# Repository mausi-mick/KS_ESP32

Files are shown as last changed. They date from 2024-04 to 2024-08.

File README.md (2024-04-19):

   Kennlinienschreiber mit ESP32

Hier möchte ich nur kurz die ESP32-Variante vorstellen.

Die vorher beschriebenen Versionen  -  auf Arduino NANO / ATMega328P   bzw. Arduino-EVERY basierend   - waren im Laufe der Entwicklung in mehrerer Hinsicht an ihre Grenzen gestossen:

    •     zu wenig Speicher
    •     zu wenig Pins
    •     relativ langsam
    •     Bluetooth nur über externe HW (HC05 /HC12)

Die ersten Tests waren dann aber etwas ernüchternd,  

Gerade die verwandten ADC’s (MCP3204) und DAC’s MCP4822 an SPI (VSPI) machten
Probleme., aber das scheint gelöst zu sein.

Ich verwende ein ESP-Modul mit 38 Pins, um möglichst viele Pins zur Verfügung zu haben für
die BUSSE (I2C, SPI), Schalter und Encoder und  RX/TX (z.B. zur Verbindung mit modif. Transistortester)

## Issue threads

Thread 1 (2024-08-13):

Guide for build

enzodello, 2024-08-13:
do I have to connect all the diagrams in the folder together?
which sketch should i load on esp32?
 could you describe what each .ino file is for?

mausi-mick, 2024-08-13:
Ad first You need the new Arduino IDE 2.3.2 ( I used version 1.8.13, but it was very slow) for the sketches ( .ino) and Header (.h) and the KiCad version 8.0 or higher for the schematics, pcbs, .

there are 3 "big" boards,

  ESP32_R ...      for the ESP32 (38 pin)
  UCE_Board_2  iwith DAC (for Uce / Uds) and the ADC and Power Amplifier TCA03722
  CCS_I2C         for the isolated precision Currentsource

and 2 small boards piggyback on the CCS_I2C board:

 CCS_Switch_BE_1            smallBoard with 4Photomos-Relais
 IC2_Adum_MCP4725_1  small Board with Adum-Isolator and DAC_MCP4725

Closed 2024-08-13.

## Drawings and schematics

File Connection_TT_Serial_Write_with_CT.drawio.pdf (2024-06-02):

# Connection AVR Transistor-Tester with Curve-Tracer

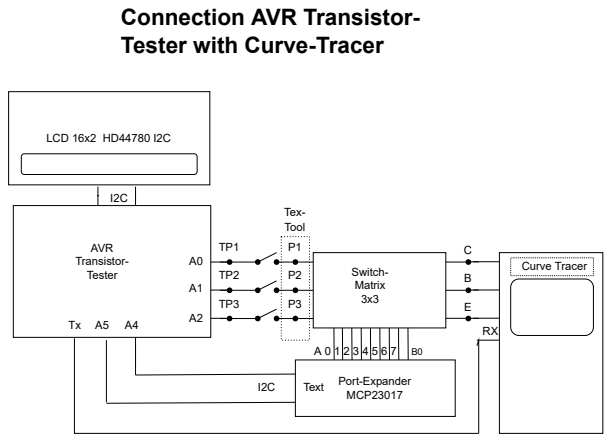
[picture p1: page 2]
Switch- Matrix 3x3; AVR Transistor- Tester; LCD 16x2 HD44780 I2C; Port-Expander; MCP23017 I2C; Text; Tex- Tool; Curve Tracer

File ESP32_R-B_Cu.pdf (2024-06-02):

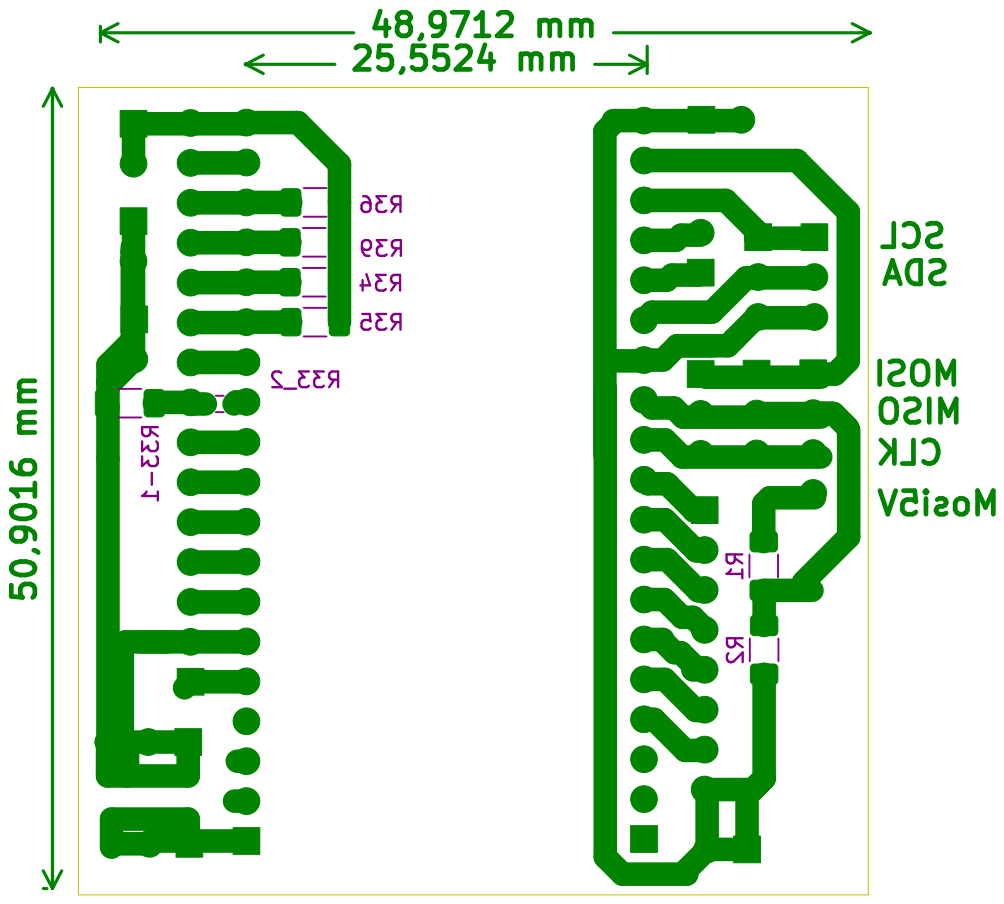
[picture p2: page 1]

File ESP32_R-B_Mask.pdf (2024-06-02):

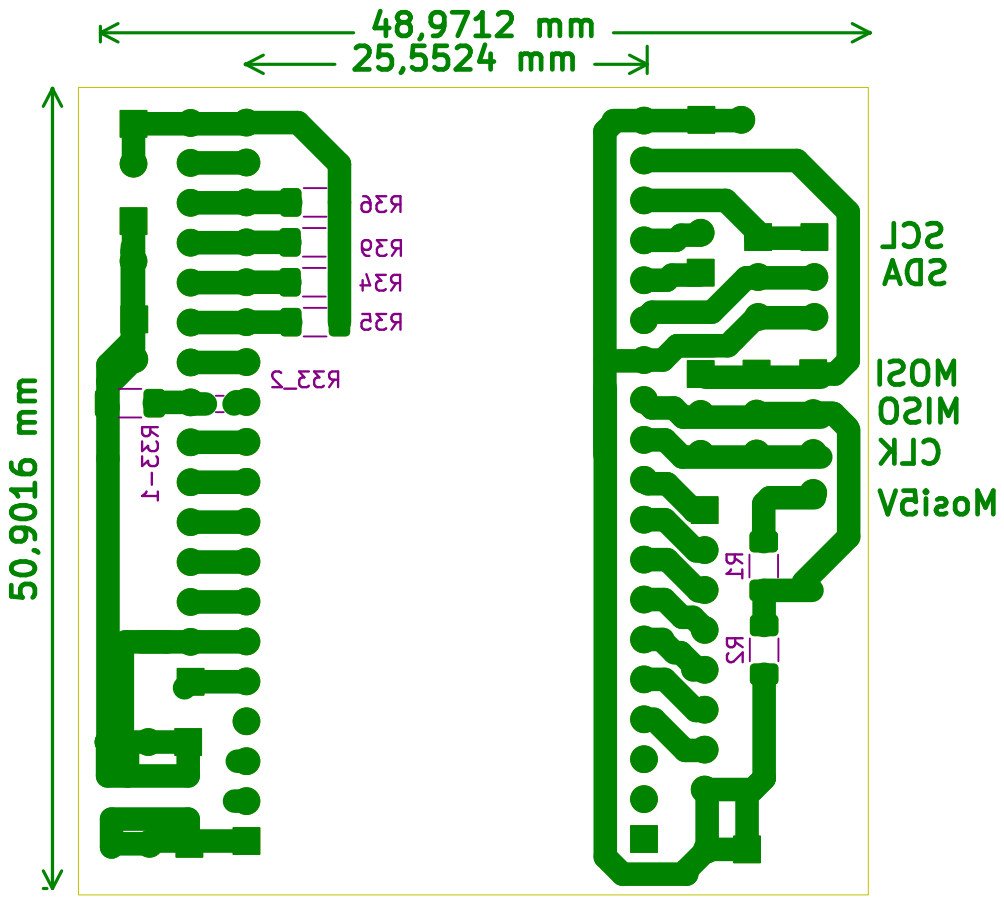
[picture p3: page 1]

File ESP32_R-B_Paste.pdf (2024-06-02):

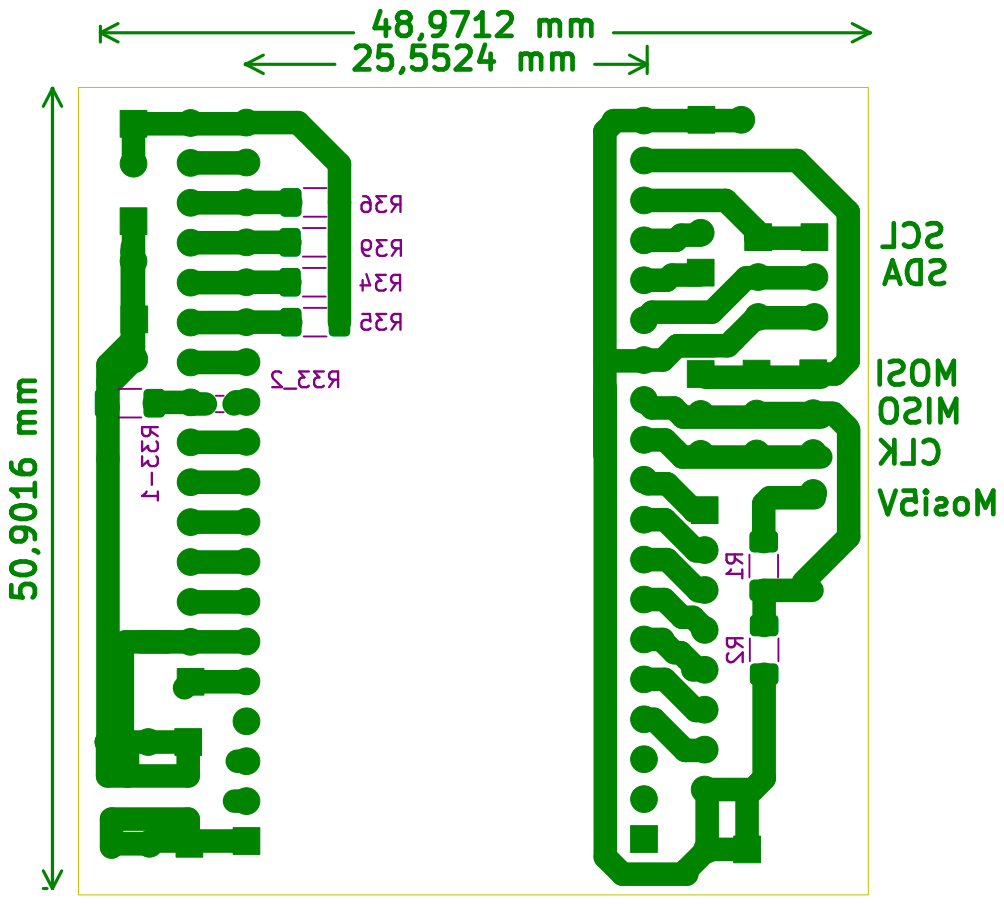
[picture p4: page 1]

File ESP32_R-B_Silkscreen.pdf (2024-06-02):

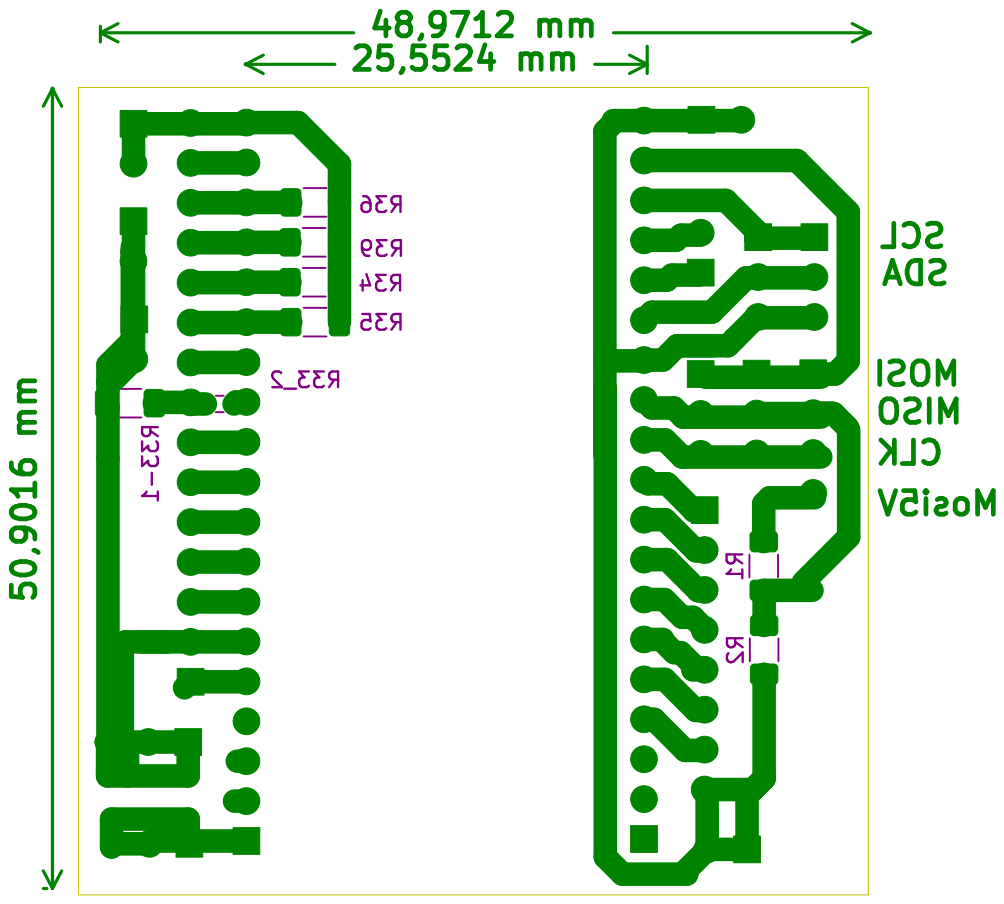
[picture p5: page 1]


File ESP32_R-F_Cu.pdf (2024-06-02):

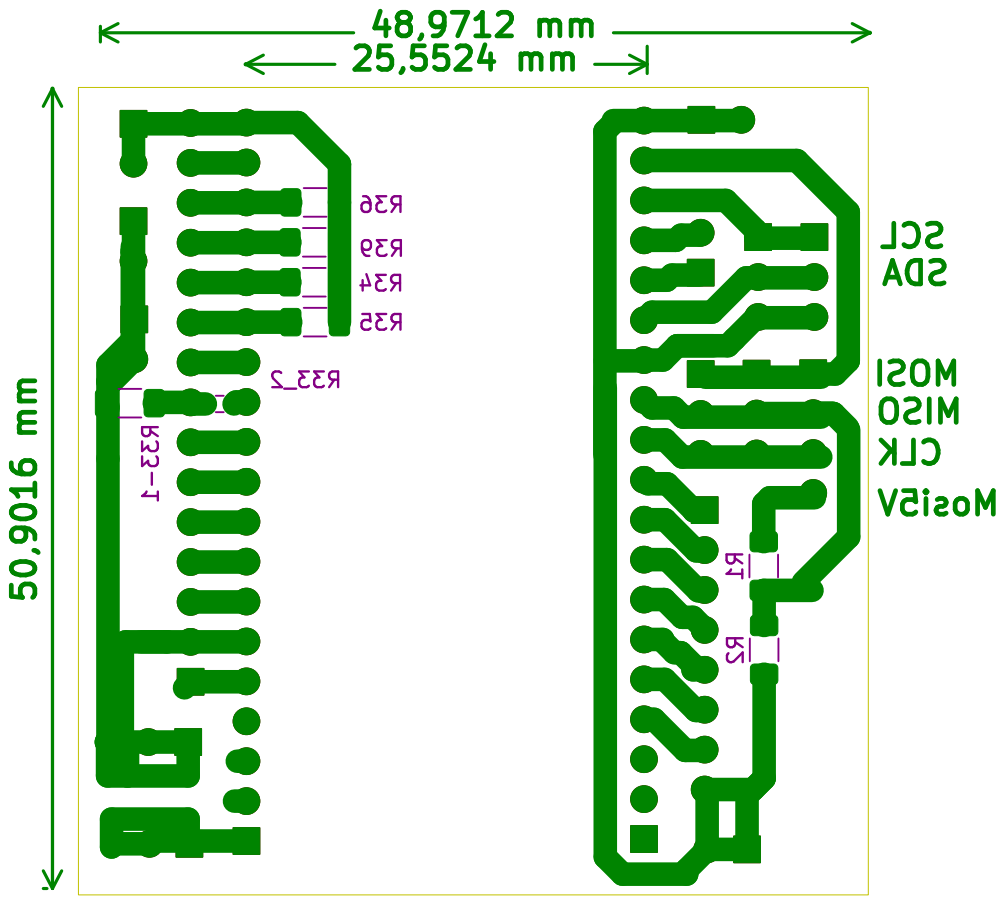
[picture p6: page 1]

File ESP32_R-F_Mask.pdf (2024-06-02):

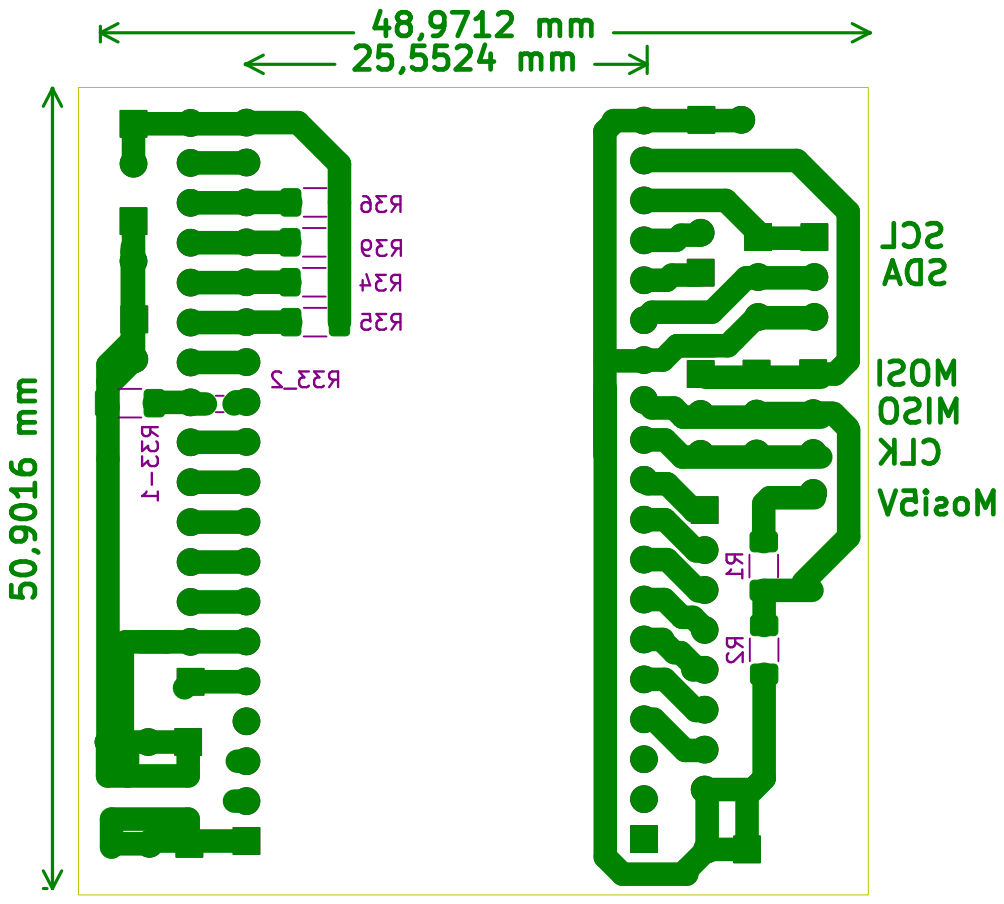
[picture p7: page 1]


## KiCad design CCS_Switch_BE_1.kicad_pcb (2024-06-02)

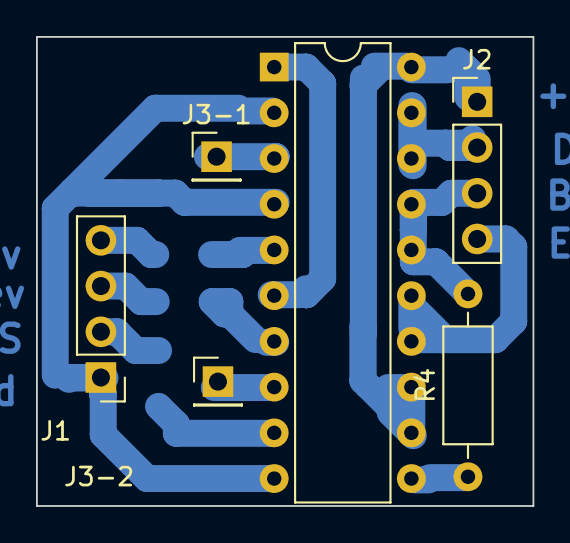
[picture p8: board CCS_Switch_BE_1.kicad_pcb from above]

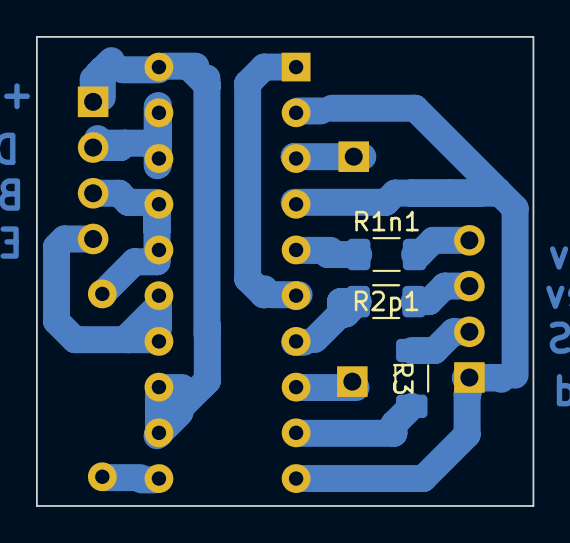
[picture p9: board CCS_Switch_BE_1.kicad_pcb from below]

Board: 2 copper layers, 27.6 x 26.1 mm, 9 parts (3 on the bottom side), 4 nets.

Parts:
DIL20: DIP-20_W7.62mm
J1: Switch n,p,Rg,Gndp; PinHeader_1x04_P2.54mm_Vertical
J2: Switch +30V,Drain-CCS,B,E; PinHeader_1x04_P2.54mm_Vertical
J3-1, J3-2: Br; PinHeader_1x01_P2.54mm_Vertical
R1n1, R2p1: 270; R_1206_3216Metric_Pad1.30x1.75mm_HandSolder
R3: 510; R_1206_3216Metric_Pad1.30x1.75mm_HandSolder
R4: 10k; R_Axial_DIN0207_L6.3mm_D2.5mm_P10.16mm_Horizontal

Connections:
unnamed: J1.2, R3.1
unnamed: J1.3, R2p1.1
unnamed: J1.4, R1n1.2
unnamed: J2.3, R4.2

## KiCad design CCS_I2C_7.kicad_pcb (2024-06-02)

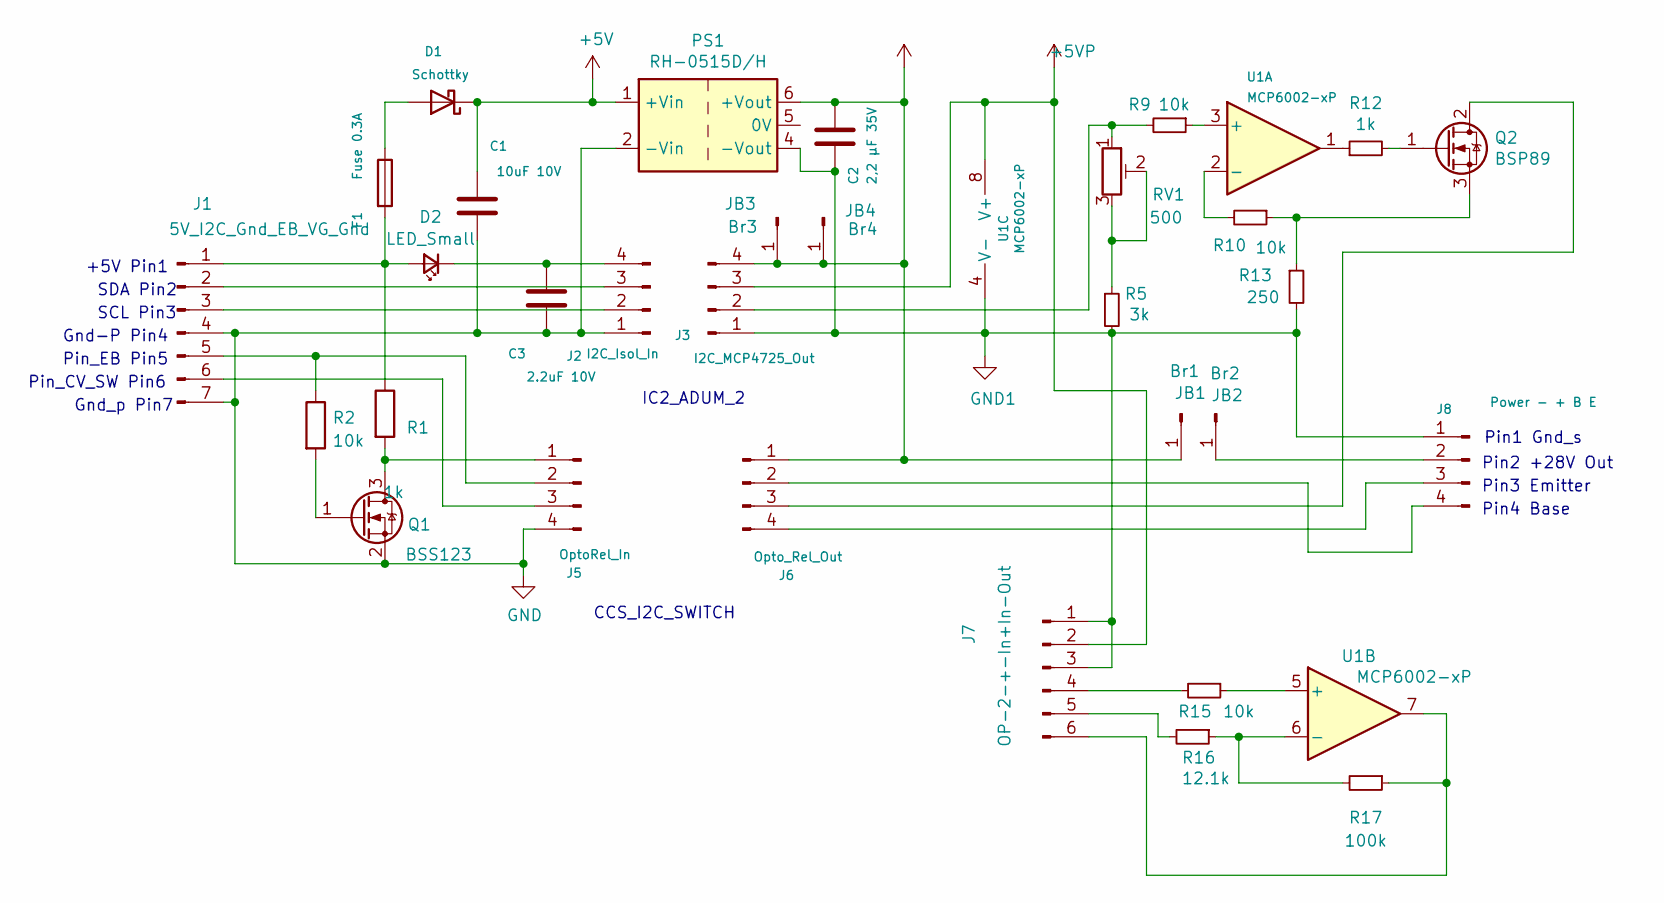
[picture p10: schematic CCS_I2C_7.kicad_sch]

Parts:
C1: 10uF 10V; C_1812_4532Metric_Pad1.57x3.40mm_HandSolder
C2: 2,2 µF 35V; C_1812_4532Metric_Pad1.57x3.40mm_HandSolder
C3: 2.2uF 10V; C_1206_3216Metric_Pad1.33x1.80mm_HandSolder
D1: Schottky; D_1206_3216Metric_Pad1.42x1.75mm_HandSolder
D2: LED_Small; LED_D3.0mm
F1: Fuse 0.3A; Fuse_1206_3216Metric_Pad1.42x1.75mm_HandSolder
J1: 5V_I2C_Gnd_EB_VG_Gnd; PinHeader_1x07_P2.54mm_Horizontal
J2: I2C_Isol_In; PinSocket_1x04_P2.54mm_Vertical
J3: I2C_MCP4725_Out; PinSocket_1x04_P2.54mm_Vertical
J5: OptoRel_In; PinSocket_1x04_P2.54mm_Vertical
J6: Opto_Rel_Out; PinSocket_1x04_P2.54mm_Vertical
J7: OP-2-+-In+In-Out; PinHeader_1x06_P2.54mm_Horizontal
J8: Power - + B E; PinHeader_1x04_P2.54mm_Horizontal
JB1: Br1; PinHeader_1x01_P2.54mm_Vertical
JB2: Br2; PinHeader_1x01_P2.54mm_Vertical
JB3: Br3; PinHeader_1x01_P2.54mm_Vertical
JB4: Br4; PinHeader_1x01_P2.54mm_Vertical
PS1: RH-0515D/H; Converter_DCDC_XP_POWER-IHxxxxSH_THT
Q1: BSS123; SOT-23
Q2: BSP89; SOT-223-3_TabPin2
R1: 1k; R_2010_5025Metric_Pad1.40x2.65mm_HandSolder
R2: 10k; R_1206_3216Metric_Pad1.30x1.75mm_HandSolder
R5: 3k; R_Axial_DIN0207_L6.3mm_D2.5mm_P10.16mm_Horizontal
R9, R10, R15: 10k; R_Axial_DIN0207_L6.3mm_D2.5mm_P10.16mm_Horizontal
R12: 1k; R_Axial_DIN0207_L6.3mm_D2.5mm_P10.16mm_Horizontal
R13: 250; R_Axial_DIN0207_L6.3mm_D2.5mm_P10.16mm_Horizontal
R16: 12.1k; R_Axial_DIN0207_L6.3mm_D2.5mm_P10.16mm_Horizontal
R17: 100k; R_Axial_DIN0207_L6.3mm_D2.5mm_P10.16mm_Horizontal
RV1: 500; Potentiometer_ACP_CA6-H2,5_Horizontal
U1: MCP6002-xP; DIP-8_W7.62mm_LongPads

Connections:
+5V: C1.1, D1.1 (K), PS1.1 (+Vin)
+5VP: J3.3, J7.2, U1.8 (V+)
+28V: C2.1, J3.4, J6.1, JB1.1, JB3.1, JB4.1, PS1.6 (+Vout)
GND: C1.2, C3.2, J1.4, J1.7, J2.1, J5.4, PS1.2 (-Vin), Q1.2 (S)
GND1: C2.2, J3.1, J7.1, J7.3, J8.1, PS1.4 (-Vout), R5.2, R13.2, U1.4 (V-)
unnamed: D1.2 (A), F1.1
unnamed: D2.2 (A), F1.2, J1.1, R1.1
unnamed: C3.1, D2.1 (K), J2.4
unnamed: J1.2, J2.3
unnamed: J1.3, J2.2
unnamed: J1.5, J5.2, R2.1
unnamed: J1.6, J5.3
unnamed: J3.2, R9.2, RV1.1
unnamed: J5.1, Q1.3 (D), R1.2
unnamed: J6.2, J8.4
unnamed: J6.3, Q2.2 (D)
unnamed: J6.4, J8.3
unnamed: J7.4, R15.2
unnamed: J7.5, R16.2
unnamed: J7.6, R17.1, U1.7
unnamed: J8.2, JB2.1
unnamed: Q1.1 (G), R2.2
unnamed: Q2.1 (G), R12.2
unnamed: Q2.3 (S), R10.1, R13.1
unnamed: R5.1, RV1.2, RV1.3
unnamed: R12.1, U1.1
unnamed: R9.1, U1.3 (+)
unnamed: R10.2, U1.2 (-)
unnamed: R15.1, U1.5 (+)
unnamed: R16.1, R17.2, U1.6 (-)

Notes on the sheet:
Pin_EB Pin5
IC2_ADUM_2
+5V Pin1
Gnd-P Pin4
SDA Pin2
Pin2 +28V Out
SCL Pin3
Pin4 Base
Gnd_p Pin7
Pin1 Gnd_s
Pin3 Emitter
CCS_I2C_SWITCH
Pin_CV_SW Pin6

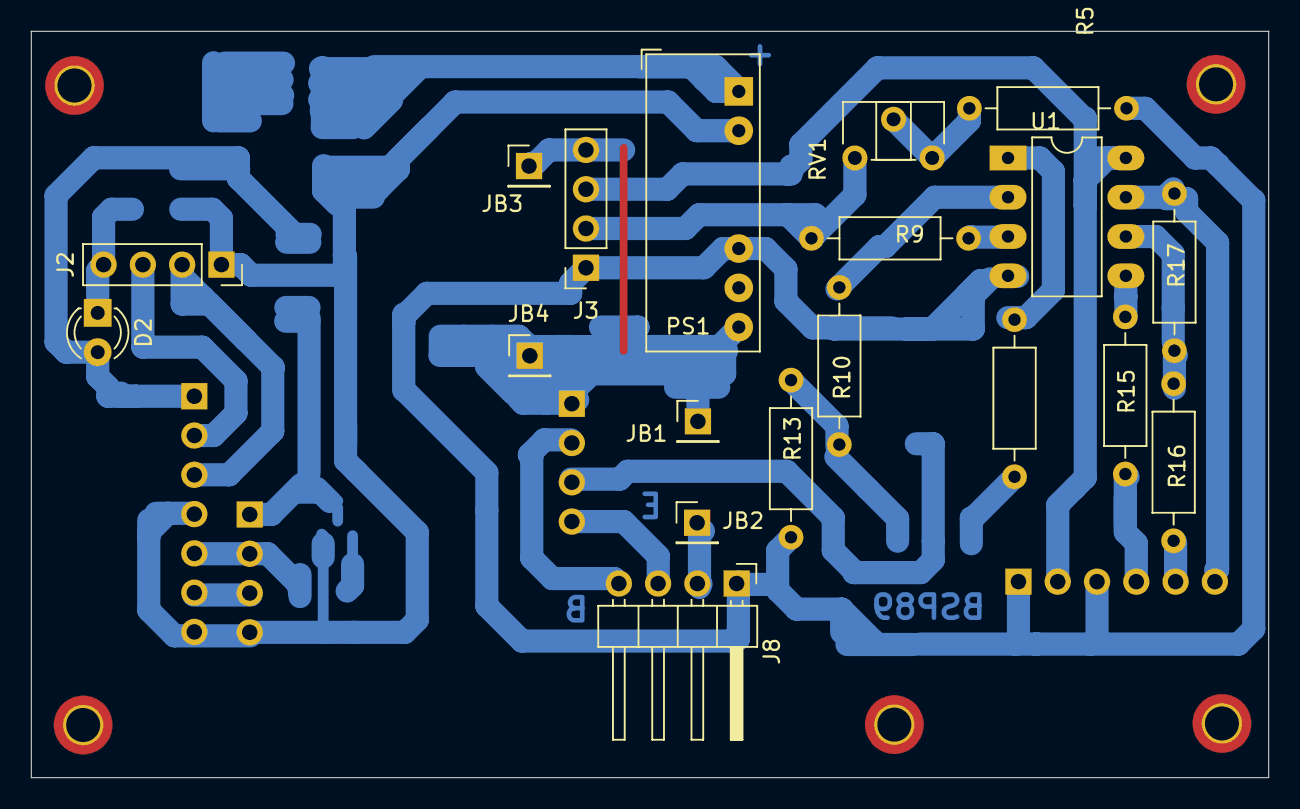
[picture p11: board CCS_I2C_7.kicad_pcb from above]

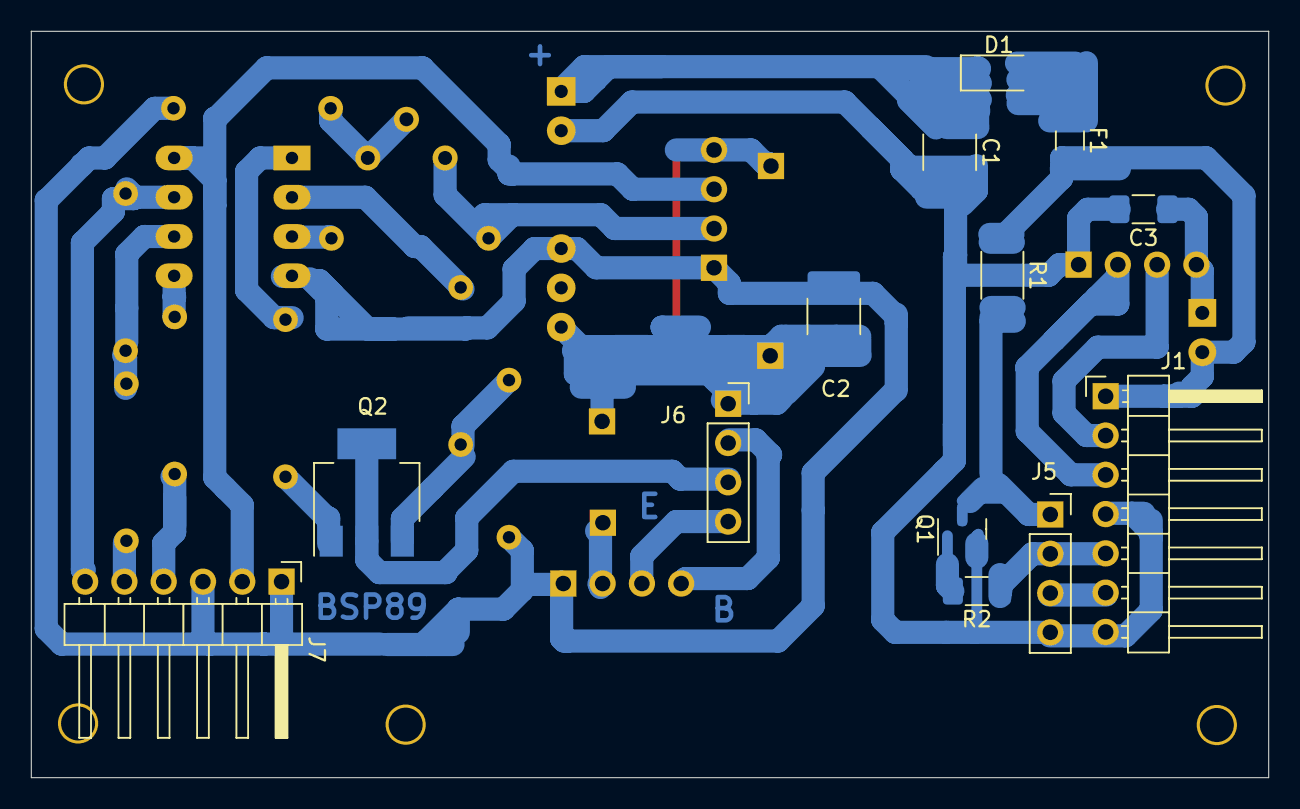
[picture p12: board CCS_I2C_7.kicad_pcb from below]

Board: 2 copper layers, 80.0 x 48.3 mm, 32 parts (13 on the bottom side), 30 nets.

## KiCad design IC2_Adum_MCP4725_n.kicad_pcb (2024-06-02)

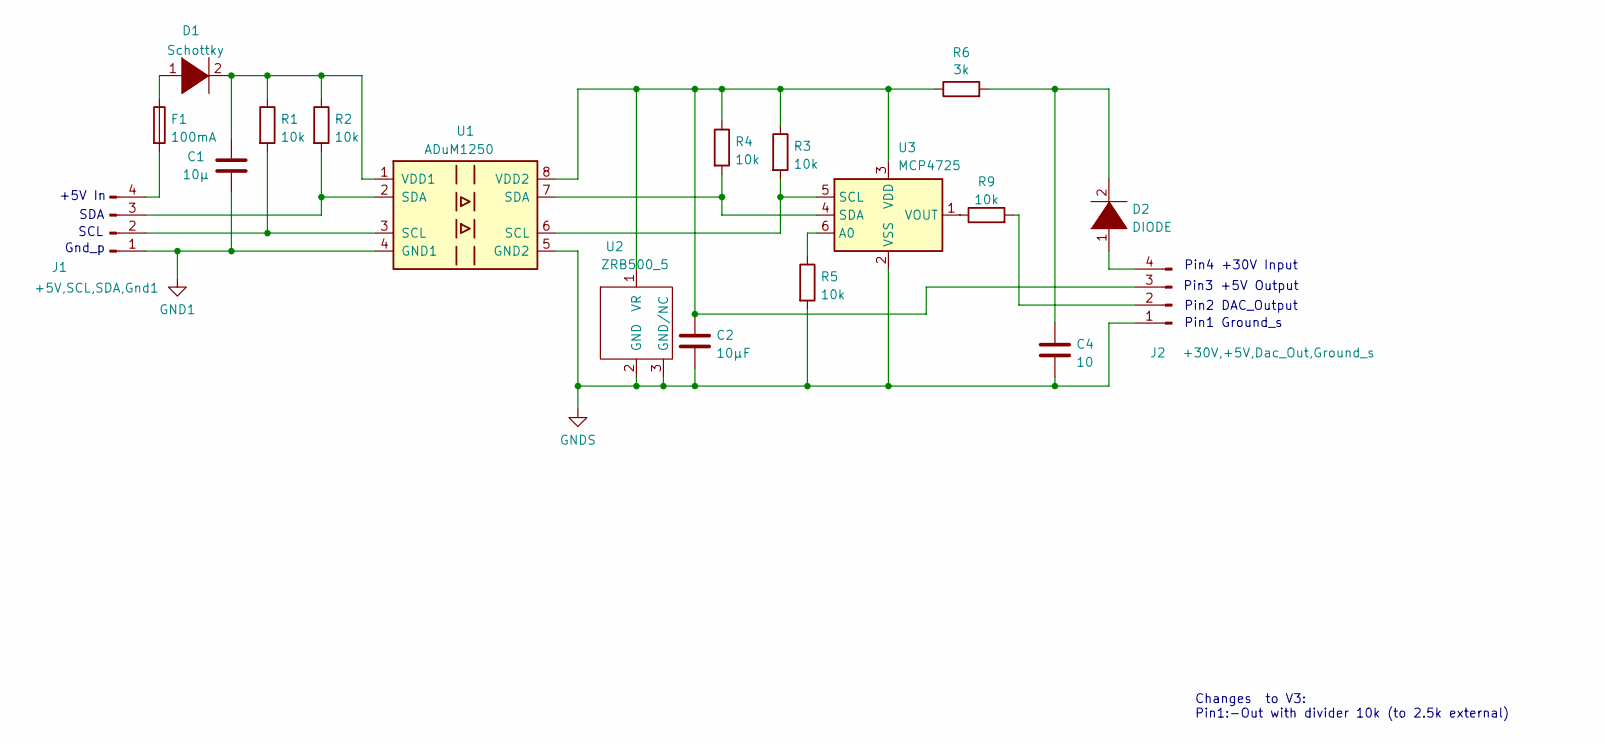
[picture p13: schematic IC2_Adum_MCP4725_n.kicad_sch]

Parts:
C1: 10µ; C_1206_3216Metric_Pad1.33x1.80mm_HandSolder
C2: 10µF; C_1206_3216Metric_Pad1.33x1.80mm_HandSolder
C4: 10; C_1206_3216Metric_Pad1.33x1.80mm_HandSolder
D1: Schottky; D_1206_3216Metric_Pad1.42x1.75mm_HandSolder
D2: DIODE; D_0805_2012Metric_Pad1.15x1.40mm_HandSolder
F1: 100mA; Fuse_1206_3216Metric_Pad1.42x1.75mm_HandSolder
J1: +5V,SCL,SDA,Gnd1; PinHeader_1x04_P2.54mm_Vertical
J2: +30V,+5V,Dac_Out,Ground_s; PinHeader_1x04_P2.54mm_Vertical
R1, R2, R3, R4, R5, R9: 10k; R_1206_3216Metric_Pad1.30x1.75mm_HandSolder
R6: 3k; R_1206_3216Metric_Pad1.30x1.75mm_HandSolder
U1: ADuM1250; SOIC-8_3.9x4.9mm_P1.27mm
U2: ZRB500_5; SOT-23-3
U3: MCP4725; SOT-23-6

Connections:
GND1: C1.2, J1.1, U1.4 (GND1)
GNDS: C2.2, C4.2, J2.1, R5.2, U1.5 (GND2), U2.2 (GND), U2.3 (GND/NC), U3.2 (VSS)
unnamed: C1.1, D1.2 (A), R1.1, R2.1, U1.1 (VDD1)
unnamed: D1.1 (K), F1.1
unnamed: C4.1, D2.2 (A), R6.2
unnamed: D2.1 (K), J2.4
unnamed: J1.2, R1.2, U1.3 (SCL)
unnamed: J1.3, R2.2, U1.2 (SDA)
unnamed: F1.2, J1.4
unnamed: J2.2, R9.2
unnamed: C2.1, J2.3, R3.1, R4.1, R6.1, U1.8 (VDD2), U2.1 (VR), U3.3 (VDD)
unnamed: R5.1, U3.6 (A0)
unnamed: R3.2, U1.6 (SCL), U3.5 (SCL)
unnamed: R4.2, U1.7 (SDA), U3.4 (SDA)
unnamed: R9.1, U3.1 (VOUT)

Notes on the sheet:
Pin2 DAC_Output
Changes to V3: Pin1:-Out with divider 10k (to 2.5k external)
+5V In
Pin3 +5V Output
Gnd_p
SDA
Pin1 Ground_s
SCL
Pin4 +30V Input

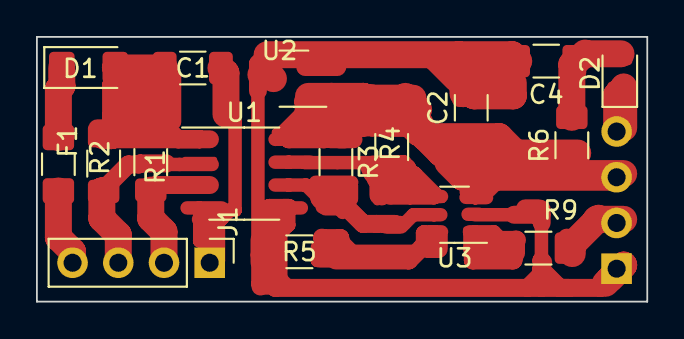
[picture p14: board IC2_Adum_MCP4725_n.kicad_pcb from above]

Board: 2 copper layers, 33.9 x 14.7 mm, 18 parts (1 on the bottom side), 15 nets.

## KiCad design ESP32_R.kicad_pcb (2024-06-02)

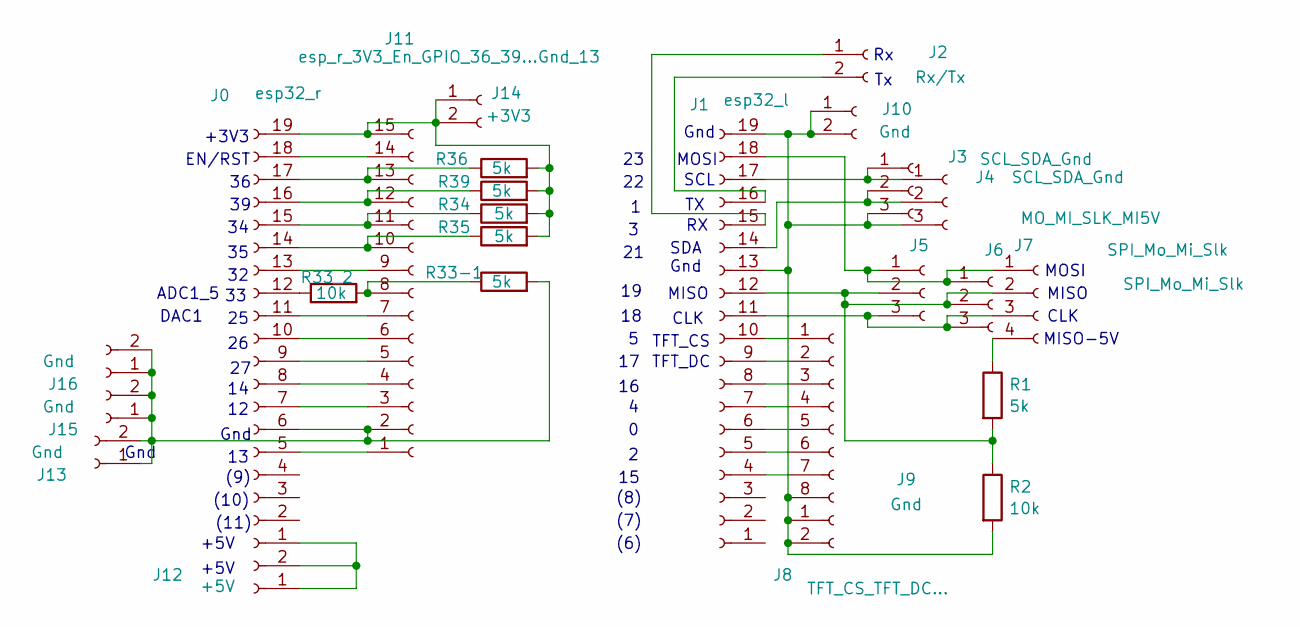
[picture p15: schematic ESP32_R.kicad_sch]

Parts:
J0: esp32_r; PinSocket_1x19_P2.54mm_Vertical
J1: esp32_l; PinSocket_1x19_P2.54mm_Vertical
J2: Rx/Tx; PinSocket_1x02_P2.54mm_Vertical
J3, J4: SCL_SDA_Gnd; PinSocket_1x03_P2.54mm_Vertical
J5, J6: SPI_Mo_Mi_Slk; PinSocket_1x03_P2.54mm_Vertical
J7: MO_MI_SLK_MI5V; PinHeader_1x04_P2.54mm_Vertical
J8: TFT_CS_TFT_DC...; PinSocket_1x08_P2.54mm_Vertical
J9, J10, J13, J15, J16: Gnd; PinSocket_1x02_P2.54mm_Vertical
J11: esp_r_3V3_En_GPIO_36_39...Gnd_13; PinHeader_1x15_P2.54mm_Vertical
J12: +5V; PinSocket_1x02_P2.54mm_Vertical
J14: +3V3; PinSocket_1x02_P2.54mm_Vertical
R1, R33-1, R34, R35, R36, R39: 5k; R_1206_3216Metric_Pad1.30x1.75mm_HandSolder
R2: 10k; R_1206_3216Metric_Pad1.30x1.75mm_HandSolder
R33_2: 10k; R_0603_1608Metric_Pad0.98x0.95mm_HandSolder

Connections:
unnamed: J0.1, J12.1, J12.2
unnamed: J0.5, J11.1
unnamed: J0.6, J11.2, J13.1, J13.2, J15.1, J15.2, J16.1, J16.2, R33-1.2
unnamed: J0.7, J11.3
unnamed: J0.8, J11.4
unnamed: J0.9, J11.5
unnamed: J0.10, J11.6
unnamed: J0.11, J11.7
unnamed: J0.12, R33_2.1
unnamed: J0.13, J11.9
unnamed: J0.14, J11.10, R35.1
unnamed: J0.15, J11.11, R34.1
unnamed: J0.16, J11.12, R39.1
unnamed: J0.17, J11.13, R36.1
unnamed: J0.18, J11.14
unnamed: J0.19, J11.15, J14.1, J14.2, R34.2, R35.2, R36.2, R39.2
unnamed: J1.4, J8.7
unnamed: J1.5, J8.6
unnamed: J1.6, J8.5
unnamed: J1.7, J8.4
unnamed: J1.8, J8.3
unnamed: J1.9, J8.2
unnamed: J1.10, J8.1
unnamed: J1.11, J5.3, J6.3, J7.3
unnamed: J1.12, J5.2, J6.2, J7.2, R1.2, R2.1
unnamed: J1.13, J1.19, J3.3, J4.3, J8.8, J9.1, J9.2, J10.1, J10.2, R2.2
unnamed: J1.14, J3.2, J4.2
unnamed: J1.15, J2.1
unnamed: J1.16, J2.2
unnamed: J1.17, J3.1, J4.1
unnamed: J1.18, J5.1, J6.1, J7.1
unnamed: J7.4, R1.1
unnamed: J11.8, R33-1.1, R33_2.2

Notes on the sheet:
Gnd
EN/RST
MOSI
TFT_CS
(10)
ADC1_5
MISO-5V
CLK
(6)
DAC1
(7)
(11)
TFT_DC
MISO
(8)
(9)
SDA
SCL
+3V3
+5V

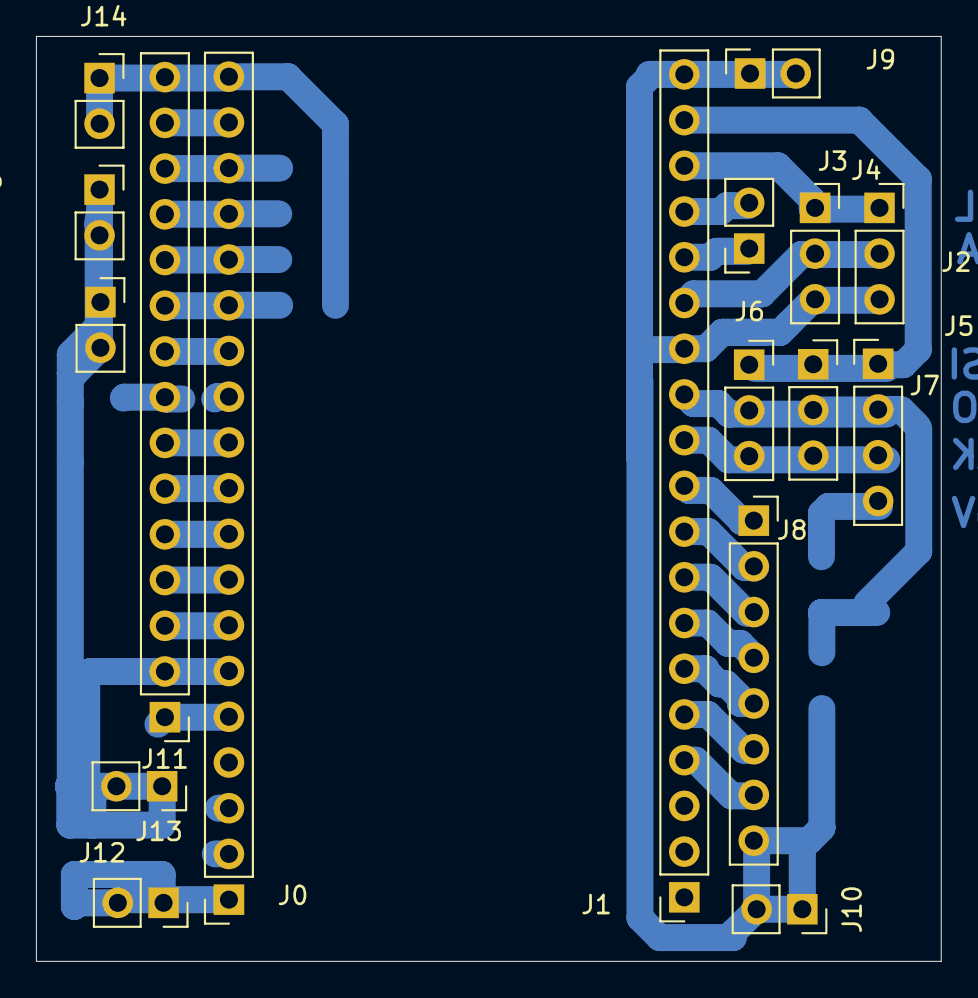
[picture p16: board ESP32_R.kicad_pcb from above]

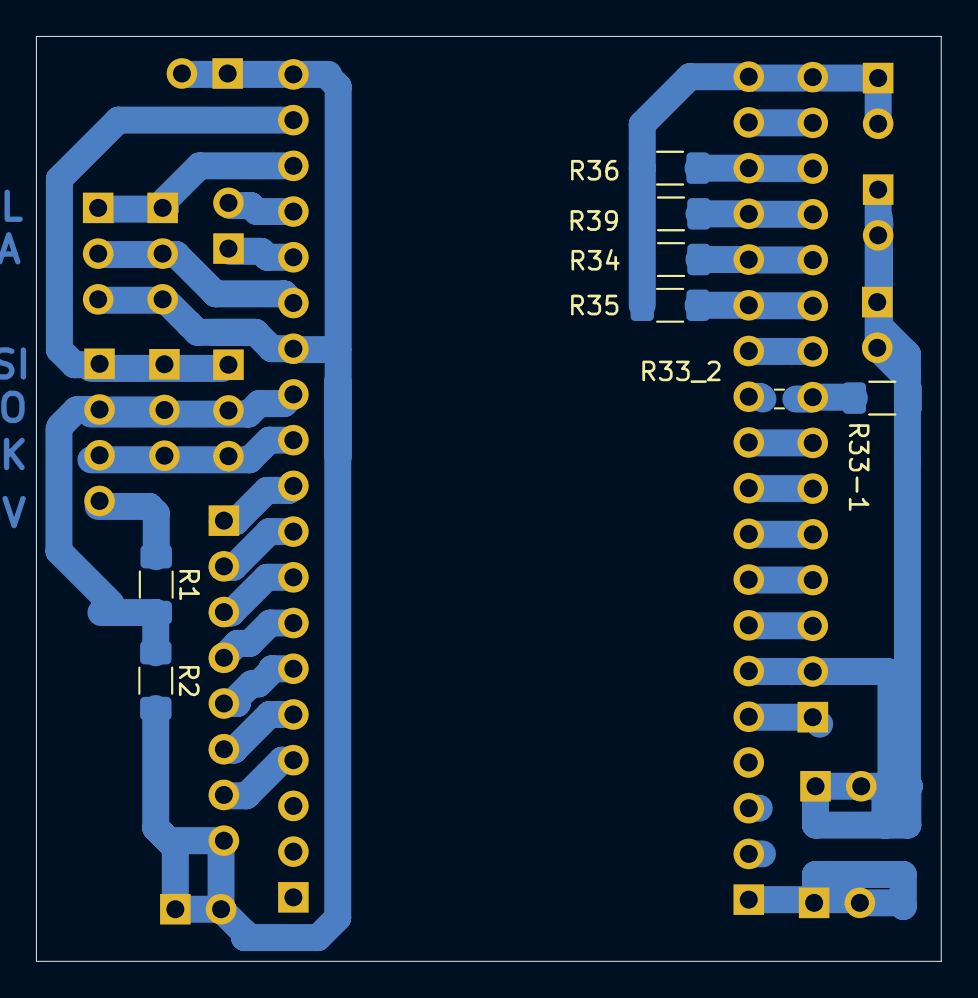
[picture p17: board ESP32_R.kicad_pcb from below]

Board: 2 copper layers, 50.3 x 51.4 mm, 25 parts (8 on the bottom side), 33 nets.

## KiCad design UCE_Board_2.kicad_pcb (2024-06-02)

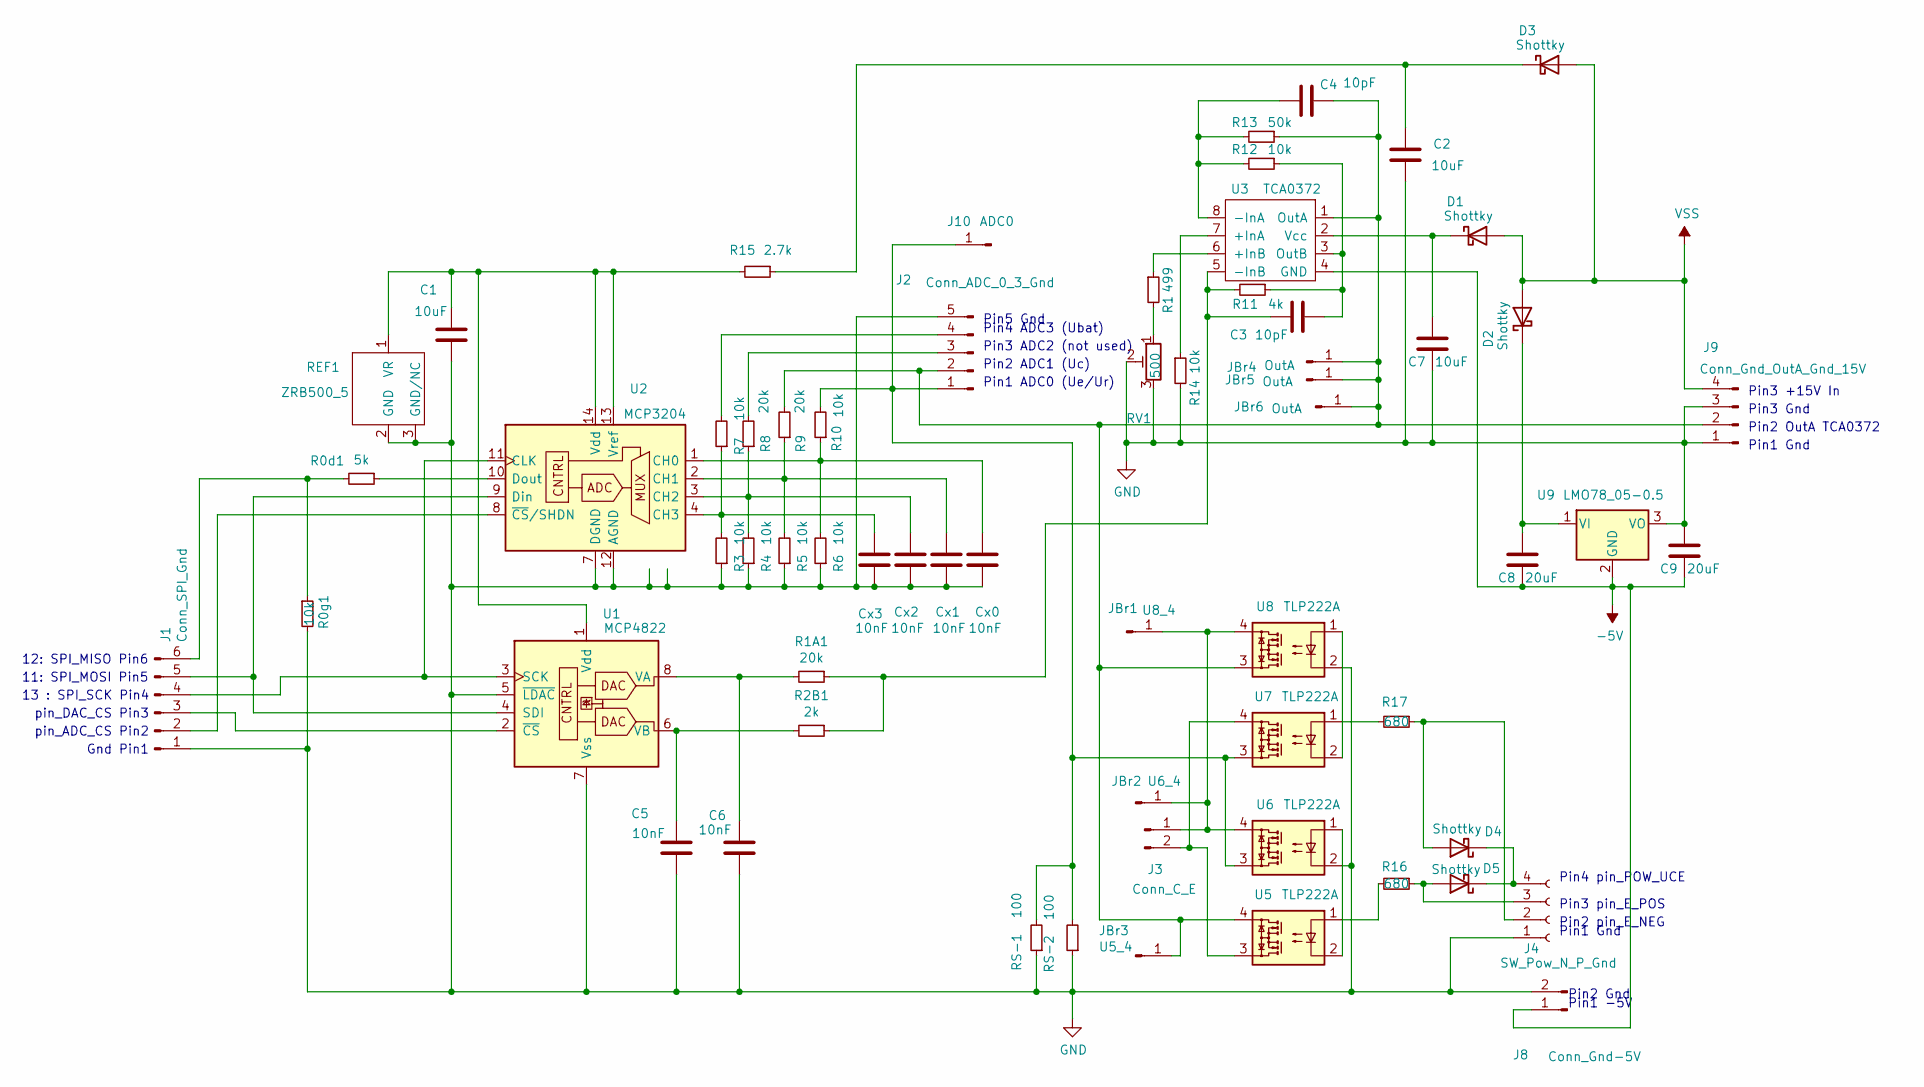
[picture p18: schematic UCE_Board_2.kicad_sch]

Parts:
C1: 10uF; C_1210_3225Metric_Pad1.33x2.70mm_HandSolder
C2: 10uF; C_1812_4532Metric_Pad1.57x3.40mm_HandSolder
C3: 10pF; C_Axial_L5.1mm_D3.1mm_P7.50mm_Horizontal
C4: 10pF; C_Rect_L9.0mm_W2.5mm_P7.50mm_MKT
C5, C6: 10nF; C_1206_3216Metric_Pad1.33x1.80mm_HandSolder
C7: 10uF; C_1206_3216Metric_Pad1.33x1.80mm_HandSolder
C8, C9: 20uF; C_1812_4532Metric_Pad1.57x3.40mm_HandSolder
Cx0, Cx1, Cx2, Cx3: 10nF; C_0805_2012Metric_Pad1.18x1.45mm_HandSolder
D1, D2, D3: Shottky; D_1206_3216Metric_Pad1.42x1.75mm_HandSolder
D4, D5: Shottky; D_0603_1608Metric_Pad1.05x0.95mm_HandSolder
J1: Conn_SPI_Gnd; PinHeader_1x06_P2.54mm_Horizontal
J2: Conn_ADC_0_3_Gnd; PinHeader_1x05_P2.54mm_Vertical
J3: Conn_C_E; PinHeader_1x02_P2.54mm_Horizontal
J4: SW_Pow_N_P_Gnd; PinHeader_1x04_P2.54mm_Horizontal
J8: Conn_Gnd-5V; PinHeader_1x02_P2.54mm_Vertical
J9: Conn_Gnd_OutA_Gnd_15V; PinHeader_1x04_P2.54mm_Horizontal
J10: ADC0; PinHeader_1x01_P2.54mm_Vertical
JBr1: U8_4; PinHeader_1x01_P2.54mm_Vertical
JBr2: U6_4; PinHeader_1x01_P2.54mm_Vertical
JBr3: U5_4; PinHeader_1x01_P1.00mm_Vertical
JBr4: OutA; PinHeader_1x01_P1.00mm_Vertical
JBr5, JBr6: OutA; PinHeader_1x01_P1.27mm_Vertical
R0d1: 5k; R_1206_3216Metric_Pad1.30x1.75mm_HandSolder
R0g1, R12: 10k; R_Axial_DIN0204_L3.6mm_D1.6mm_P7.62mm_Horizontal
R1: 499; R_Axial_DIN0207_L6.3mm_D2.5mm_P10.16mm_Horizontal
R1A1: 20k; R_Axial_DIN0207_L6.3mm_D2.5mm_P10.16mm_Horizontal
R2B1: 2k; R_Axial_DIN0207_L6.3mm_D2.5mm_P10.16mm_Horizontal
R3, R4, R5, R6, R7, R10: 10k; R_1206_3216Metric_Pad1.30x1.75mm_HandSolder
R8, R9: 20k; R_1206_3216Metric_Pad1.30x1.75mm_HandSolder
R11: 4k; R_Axial_DIN0207_L6.3mm_D2.5mm_P10.16mm_Horizontal
R13: 50k; R_Axial_DIN0207_L6.3mm_D2.5mm_P10.16mm_Horizontal
R14: 10k; R_Axial_DIN0207_L6.3mm_D2.5mm_P10.16mm_Horizontal
R15: 2.7k; R_Axial_DIN0207_L6.3mm_D2.5mm_P10.16mm_Horizontal
R16, R17: 680; R_Axial_DIN0207_L6.3mm_D2.5mm_P10.16mm_Horizontal
REF1: ZRB500_5; SOT-23
RS-1, RS-2: 100; R_Axial_DIN0207_L6.3mm_D2.5mm_P10.16mm_Horizontal
RV1: 500; Potentiometer_ACP_CA9-H2,5_Horizontal
U1: MCP4822; DIP-8_W7.62mm_LongPads
U2: MCP3204; DIP-14_W7.62mm
U3: TCA0372; DIP-8_W7.62mm_LongPads
U5, U6, U7, U8: TLP222A; DIP-4_W7.62mm
U9: LMO78_05-0.5; TO-220-3_Vertical

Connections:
-5V: C8.2, C9.2, J8.1, U3.4 (GND), U9.2 (GND)
GND: C1.2, C2.2, C5.1, C6.1, C7.2, C9.1, Cx0.1, Cx1.1, Cx2.1, Cx3.1, J1.1, J2.5, J4.1, J8.2, J9.1, J9.3, R0g1.2, R3.1, R4.1, R5.1, R6.1, R14.2, REF1.2 (GND), REF1.3 (GND/NC), RS-1.1, RS-2.1, RV1.2, RV1.3, U1.5 (~LDAC), U1.7 (Vss), U2.5 (NC), U2.6 (NC), U2.7 (DGND), U2.12 (AGND), U6.2, U8.2, U9.3 (VO)
unnamed: C7.1, D1.1 (K), U3.2 (Vcc)
unnamed: C8.1, D2.1 (K), U9.1 (VI)
unnamed: C2.1, D3.1 (K), R15.1
unnamed: D4.2 (A), J4.2, R17.1
unnamed: D4.1 (K), D5.1 (K), J4.4
unnamed: D5.2 (A), J4.3, R16.1
unnamed: J1.2, U2.8 (~CS/SHDN)
unnamed: J1.3, U1.2 (~CS)
unnamed: J1.4, U1.3 (SCK), U2.11 (CLK)
unnamed: J1.5, U1.4 (SDI), U2.9 (Din)
unnamed: J1.6, R0d1.2, R0g1.1
unnamed: C4.1, J2.2, J9.2, JBr3.1, JBr4.1, JBr5.1, JBr6.1, R9.2, R13.1, U3.1 (OutA), U5.4, U8.3
unnamed: J2.3, R8.2
unnamed: J2.4, R7.2
unnamed: J3.1, JBr1.1, JBr2.1, U6.4, U8.4
unnamed: J3.2, U5.3, U7.4
unnamed: J2.1, J10.1, R10.2, RS-1.2, RS-2.2, U6.3, U7.3
unnamed: R1.2, RV1.1
unnamed: R16.2, U5.1
unnamed: R17.2, U7.1
unnamed: C1.1, R15.2, REF1.1 (VR), U1.1 (Vdd), U2.13 (Vref), U2.14 (Vdd)
unnamed: C6.2, R1A1.2, U1.8 (VA)
unnamed: C5.2, R2B1.2, U1.6 (VB)
unnamed: Cx0.2, R6.2, R10.1, U2.1 (CH0)
unnamed: Cx1.2, R5.2, R9.1, U2.2 (CH1)
unnamed: Cx2.2, R4.2, R8.1, U2.3 (CH2)
unnamed: Cx3.2, R3.2, R7.1, U2.4 (CH3)
unnamed: R0d1.1, U2.10 (Dout)
unnamed: R14.1, U3.7 (+InA)
unnamed: R1.1, U3.6 (+InB)
unnamed: C4.2, R12.2, R13.2, U3.8 (-InA)
unnamed: C3.2, R1A1.1, R2B1.1, R11.2, U3.5 (-InB)
unnamed: C3.1, R11.1, R12.1, U3.3 (OutB)
unnamed: U5.2, U6.1
unnamed: U7.2, U8.1
VSS: D1.2 (A), D2.2 (A), D3.2 (A), J9.4

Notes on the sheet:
pin_ADC_CS Pin2
Pin1 Gnd
Pin5 Gnd
Gnd Pin1
Pin2 pin_E_NEG
Pin2 OutA TCA0372
Pin4 pin_POW_UCE
12: SPI_MISO Pin6
Pin2 ADC1 (Uc)
pin_DAC_CS Pin3
Pin3 pin_E_POS
Pin3 ADC2 (not used)
Pin2 Gnd
Pin1 ADC0 (Ue/Ur)
Pin3 +15V In
Pin1 -5V
Pin3 Gnd
11: SPI_MOSI Pin5
Pin4 ADC3 (Ubat)
13 : SPI_SCK Pin4

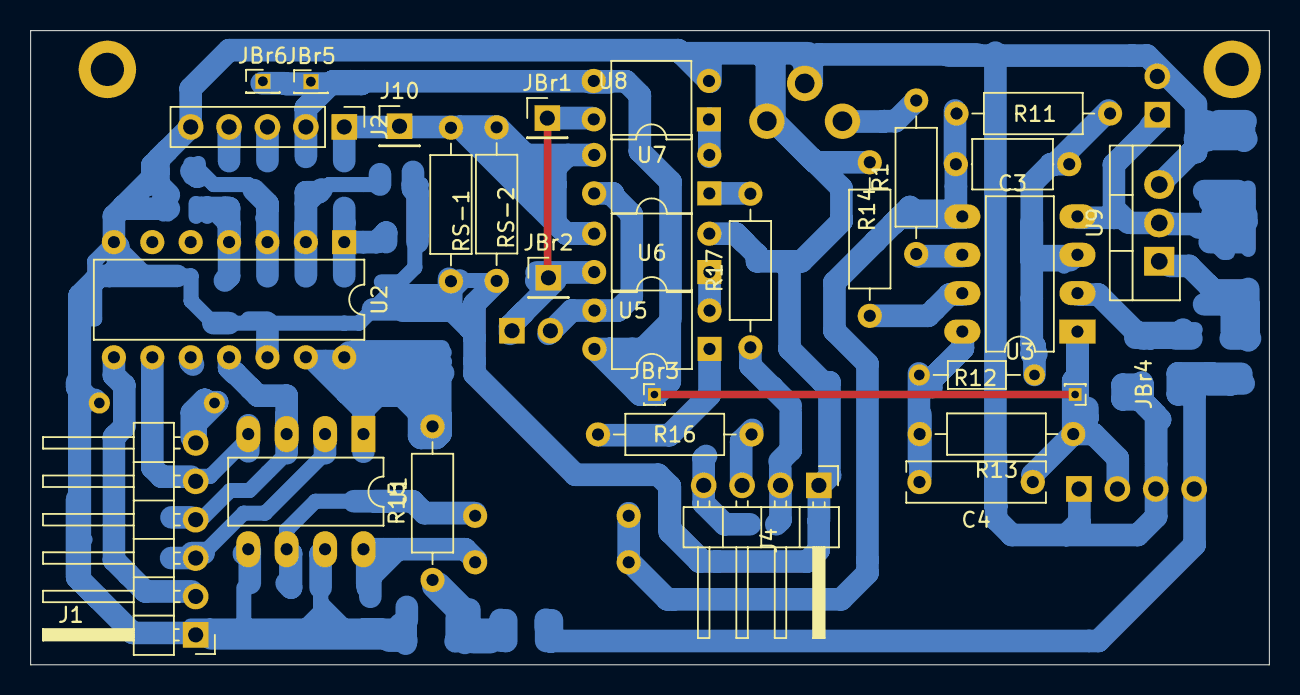
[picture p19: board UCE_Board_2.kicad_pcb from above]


Board: 2 copper layers, 82.0 x 42.0 mm, 63 parts (33 on the bottom side), 38 nets.

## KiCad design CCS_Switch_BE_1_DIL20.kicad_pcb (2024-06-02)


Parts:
J1: Switch n,p,Rg,Gndp; PinHeader_1x04_P2.54mm_Vertical
J2: Switch +30V,Drain-CCS,B,E; PinHeader_1x04_P2.54mm_Vertical
J3-1, J3-2: Br; PinHeader_1x01_P2.54mm_Vertical
R1n1, R2p1: 270; R_1206_3216Metric_Pad1.30x1.75mm_HandSolder
R3: 510; R_1206_3216Metric_Pad1.30x1.75mm_HandSolder
R4: 10k; R_Axial_DIN0207_L6.3mm_D2.5mm_P10.16mm_Horizontal
SW1, SW2, SW3, SW4, SW5: TLP222A; DIP-4_W7.62mm

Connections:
GND: J1.1, SW1.2, SW2.2, SW5.2
unnamed: J1.2, R3.1
unnamed: J1.3, R2p1.1
unnamed: J1.4, R1n1.2
unnamed: J2.1, SW1.4, SW4.3, SW5.4
unnamed: J2.2, SW1.3, SW2.4
unnamed: J2.3, R4.2, SW2.3, SW3.4
unnamed: J2.4, SW3.3, SW4.4
unnamed: J3-1.1, SW2.1
unnamed: J3-2.1, SW4.2
unnamed: R1n1.1, SW3.1
unnamed: R2p1.2, SW4.1
unnamed: R3.2, SW5.1
unnamed: R4.1, SW5.3
unnamed: SW1.1, SW3.2

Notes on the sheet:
Base
SW_pDev
SW_CCS_CVS
SW_nDev
+30V
Drain
Emitter
Gnd



Board: 2 copper layers, 28.2 x 30.2 mm, 13 parts (3 on the bottom side), 15 nets.

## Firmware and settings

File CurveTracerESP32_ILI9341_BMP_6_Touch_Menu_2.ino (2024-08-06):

//---------------------------------------------------------------
// 
//--------------------------------------------------------------------------------------------------------------------------------------
// 2023_03_16 copy from CurveTracer_2_DacV_20, but other dividers on A0,A1,A2,A3
// 2023_03_18 second encoder, only PIN_EB (not PIN_BE) for p-devices (pin 1 CCS normal high, switch automatically to low, if PIN_EB high)
// 2023_03-21 sign µ in 2/1 on position of tile (~)
// 2024_01_04 CurveTracerRP2040_Adafruit_ILI9341_SD_01: change µ-proceesor to RP2040
// 2024_01_04 CurveTracerRP2040_Adafruit_ILI9341_SD_02: test isr and encoder ("pio_encoder")
// 2024_01_16 CurveTracerESP32_ILI9341_SD_03: SD-Card , SerialBT instead of HM010
// 2024_04_20 CurveTracerESP32_ILI9341_BMP_5: SD-Card , SerialBT, new libs for MCP3204 and MCP4822, isr update
// 2024_06_01 CurveTracerESP32_ILI9341_BMP_6: s_zen: suppress zeo-point x-scale, start curve from volt s_zen
//--------------------------------------------------------------------------------------------------------------------------------------

//#define DEBUG 1
#if DEBUG == 1
#define debug(x)   Serial.print(x);
#define debugb(x)  Serial.print(x);Serial.print(" ");
#define debugln(x) Serial.print(x);Serial.print("\n");
#define debuglf()  Serial.print("\n");
#else
#define debug(x)
#define debugb(x)
#define debugln(x)
#define debuglf()
#endif

#define TOUCH
#define DAC_INT
#define BLUE_T
#define BMP
#define IEPROM
#define SD_C
//#define NAME_D
//#define OSCI

#include <Arduino.h>

#include <SPI.h>

#ifdef SD_C
#include <SD.h>  //###################
#endif

//SPISettings settingsT(10000000, MSBFIRST, SPI_MODE0); // TFT 12 MHz, cpu 240 MHz

#include "TFT_eSPI.h"
#include "Free_Fonts.h"   // Include the header file attached to this sketch

TFT_eSPI tft = TFT_eSPI();       // Invoke custom library

#define TFT_GREY 0x5AEB

#ifdef IEPROM         // internal EEPROM
#include "EEPROM.h"
#define EEPROM_SIZE 256
#endif

#include "MCP_ADC.h"

// ESP32 PINS for HSPI :  CLK=14, MISO=12, MOSI=13
// ESP32 PINS for VSPI :  CLK=18, MISO=19, MOSI=23

MCP3204 MCP_A;    // use HWSPI  on ESP32 (apparently VSPI)

#include <Wire.h>

#include "Adafruit_MCP4725.h"

Adafruit_MCP4725 dac_i2c;        // 12 bit DAC (I2C Addrees : 60

#ifdef BLUE_T
#include "BluetoothSerial.h"
BluetoothSerial SerialBT;
#endif

//#define EEPROM_I2C_ADDRESS 0x50  // EEPROM 24LC64 I2C Address  //24LC

const int pin_DAC_CS        =  0;  // MCP4822 DAC
const int TX_D0             =  1;  // TxD0 for send data to PC
const int pin_ADC_CS        =  2;  // MCP3204 ADC//GPIO2  on board LED, must be left floating or LOW to enter flashing mode
const int RX_D0             =  3;  // RxD0 for TT
const int pin_EB            =  4;  // switch emitter / base (polarity)
//const int TFT_CS          =  5;  // V-SPI CS
//                          =  6;  // Flash
//                          =  7;  // Flash
//                          =  8;  // Flash
//                          =  9;  // Flash
//                          = 10;  // Flash
//                          = 11;  // Flash
const int pin_E_NEG         = 12;  // switch Emitter/Source/Kathode to Rs (near Gnd)   ,Collector ... to Output TCA0372)(for npn-Tran,n-MOS
//free                      = 13;  // free 
const int pin_E_POS         = 14;  // switch Emitter/Source/Kathode to (output max+12V) (for pnp-Tran,p-MOS,p-JFET,Diode(backward biased))
const int pin_CV_SW         = 15;  // switch Constant-Current to Constant-Voltage for (Mos-Fet and J-Fet)
#ifdef SD_C
const int pin_SD_CS         = 16;  // SD_CS
#endif
//const int TFT_DC          = 17;  // V-SPI DC
//const int TFT_CLK         = 18;  // V-SPI CLK
//const int TFT_MISO        = 19;  // V-SPI MISO
//                           = 20;  // ??? na
//const int I2C_SDA         = 21;  // SDA I2C for MCP4725 (DAC-base)
//const int I2C_SCL         = 22;  // SCL I2C for MCP4725 (DAC-base)
//const int TFT_MOSI        = 23;  // V-SPI MOSI
//                           = 24;  // ??? na
#ifdef OSCI
#ifdef DAC_INT 
const int pin_DAC1          = 25;  // DAC1
#endif
#endif  
const int pin_TOUCH_IRQ     = 26;  // Touch-IRQ test   // DAC2                  
const int pin_TOUCH_CS      = 27;  // Touch-CS here not used
//                           = 28;  // ??? na
//                           = 29;  // ??? na
//                           = 30;  // ??? na
//                           = 31;  // ??? na
const int Pin_32_BUT        = 32;  // PushButton  ISR-Pin
#ifdef OSCI
const int pin_ADC1_5        = 33;  // ADC1_5
#endif 
const int pin_ENC1_A        = 34;  // Encoder-1-A ISR-Pin, Pull-Up 10k ?
const int pin_ENC1_B        = 35;  // Encoder-1-B IST-Pin, Pull-Up 10k ?
const int pin_ENC2_A        = 36;  // Encoder-2-A ISR-Pin, Pull-Up 10k ?
const int pin_ENC2_B        = 39;  // Encoder-2-B ISR-Pin, Pull-Up 10k ?

const int pin_DAC_LDAC      = -1;  // MCP4822

//#include "MCP4822.h"
//MCP4822 dac = MCP4822(pin_DAC_CS);//,pin_DAC_LDAC);

#include "MCP_DAC.h"

//  HSPI uses default   SCLK=14, MISO=12, MOSI=13, SELECT=15
//  VSPI uses default   SCLK=18, MISO=19, MOSI=23, SELECT=5
SPIClass * myspi = new SPIClass(VSPI);
MCP4822 MCP_D(myspi);  // HW SPI

const int TFT_WID   =  320;
const int TFT_HGT   =  240;
#ifdef OSCI

int16_t inpBuf2[TFT_WID];
int16_t inpBuf3[TFT_WID];

uint8_t newBuf2[TFT_WID], oldBuf2[TFT_WID];
uint8_t newBuf3[TFT_WID], oldBuf3[TFT_WID];
int pos = 0;                      // the next position in the value array to read
int count = 0;                    // the total number of times through the loop
unsigned long readStartTime = 0;  // time when the current sampling started
int lastStart = 0;                // the sample at which drawing started last time (need to know this to clear the old line properly)
int16_t val_A1 = 0,val_A2,val_A3;
// Used by vsprintf.
//char buffer[32];
uint16_t SineValues[256];       // an array to store our values for sine

#endif

//const int ADC_MAX = 4095; // 12 bit MCP3402 1024; // 10 bit arduino UNO
//const int DAC_MAX = 4095;
const int tsd       = 1000;

const int mAmax       = 50; // Ic for top of screen
const int Vmax        = 12; // 12V right end of screen
const uint16_t col_t[] = {TFT_CYAN, TFT_YELLOW, TFT_MAGENTA,/* TFT_BRIGHTBLUE,*/ TFT_ORANGE,
                          TFT_PINK, /*TFT_LIGHTBLUE, TFT_LIGHTRED,*/ TFT_WHITE
                         };

const float count_to_mv   = 5020.0 / 4096.0;    // = 1.2129=Vref/maxcount ADC  //Vref = 5.02V ?? not 4.968
//const float adc_refmaxcnt = 0.0049512; //4.0*5.07/4096.0;  // MC3204  -Reference      = U-5V/12bit ADC; divider 4: 30k/10k
//const float adc0_refmaxcnt = 0.0024756; // 4949; //2.0*5.07/4096.0;  // MC3204  -Reference      = U-5V/12bit ADC; divider 2: 10k/10k A0
//const float adc1_refmaxcnt = 0.0037134; // 4949; //3.0*5.07/4096.0;  // MC3204  -Reference      = U-5V/12bit ADC; divider 3: 20k/10k A1
//const float adc_refmaxcnt = 1.110.0/1024.0;   // Internal-Reference NANO = 1.1V/10bit ADC; // divider 4.25V/1.1V ?
//const float adc_refmaxcnt = 4.41545/1024.0;   // normal  -Reference NANO = U-5V/10bit ADC; // ca 4.42V on USB
//const float adc_refmaxcnt = 4.0*5.07/4098.0;  // MC3204  -Reference      = U-5V/12bit ADC; divider
//const char seper = ',';  // seperator for Bluetooth-transfer


uint8_t bmpPNP[] PROGMEM = {
  21, 0, // width
  30, 0, // height
  0x3F, 0xFF, 0xF9, 0xFF, 0xFF, 0xCF, 0xFF, 0xFE, 0x7F, 0xFF, 0xF1, 0xFF, 0x3F, 0xC7, 0xF9, 0xFF,
  0x1F, 0xCF, 0xFC, 0x7E, 0x7F, 0xF1, 0xF3, 0xFF, 0xC7, 0x9F, 0xFF, 0x1C, 0xFF, 0xFC, 0x67, 0xFF,
  0xF1, 0x3F, 0xFF, 0xC1, 0xFF, 0xFF, 0x00, 0x1F, 0xFC, 0x00, 0xFF, 0x93, 0xFF, 0xF0, 0x9F, 0xFE,
  0x0C, 0xFF, 0xC0, 0x67, 0xFC, 0x07, 0x3F, 0xF0, 0x39, 0xFF, 0x83, 0xCF, 0xF8, 0x1E, 0x7F, 0x8D,
  0xF3, 0xF8, 0xFF, 0x9F, 0xCF, 0xFF, 0xFE, 0x7F, 0xFF, 0xF3, 0xFF, 0xFF, 0x9F, 0xFF, 0xFC
};

uint8_t bmpNPN[] PROGMEM = {
  21, 0, // width
  30, 0, // height
  0xFF, 0xFF, 0xE7, 0xFF, 0xFF, 0x3F, 0xFF, 0xF9, 0xFF, 0xFF, 0xCF, 0xE7, 0xFC, 0x7F, 0x3F, 0xC7,
  0xF9, 0xFC, 0x7F, 0xCF, 0xC7, 0xFE, 0x7C, 0x7F, 0xF3, 0xC7, 0xFF, 0x9C, 0x7F, 0xFC, 0xC7, 0xFF,
  0xE4, 0x7F, 0xFF, 0x07, 0xFC, 0x00, 0x7F, 0xE0, 0x03, 0xFF, 0xFE, 0x0F, 0xFF, 0xF2, 0x3B, 0xFF,
  0x98, 0x9F, 0xFC, 0xE0, 0x7F, 0xE7, 0x83, 0xFF, 0x38, 0x0F, 0xF9, 0x80, 0x7F, 0xCF, 0x01, 0xFE,
  0x7E, 0x0F, 0xF3, 0xFC, 0x3F, 0xFF, 0xF9, 0xFF, 0xFF, 0xCF, 0xFF, 0xFE, 0x7F, 0xFF, 0xF0
};

uint8_t bmpNMOSFET[] PROGMEM = {
  23, 0, // width
  34, 0, // height
  0xFF, 0xFF, 0xF9, 0xFF, 0xFF, 0xF3, 0xFF, 0xFF, 0xE7, 0xFF, 0xFF, 0xCF, 0xFF, 0xFF, 0x9F, 0xFF,
  0xFF, 0x3F, 0xFF, 0xFE, 0x7F, 0xFF, 0xFC, 0xFE, 0x60, 0x01, 0xFC, 0xC0, 0x03, 0xF9, 0x9F, 0xFF,
  0xF3, 0x3F, 0xFF, 0xE7, 0xFF, 0xFF, 0xCF, 0xFB, 0xFF, 0x99, 0xC7, 0xFF, 0x32, 0x0F, 0xFE, 0x60,
  0x01, 0xFC, 0xC0, 0x03, 0xF9, 0x90, 0x67, 0xF3, 0x38, 0xCF, 0xE7, 0xFD, 0x9F, 0xCF, 0xFF, 0x3F,
  0x99, 0xFE, 0x7F, 0x33, 0xFC, 0x00, 0x60, 0x00, 0x00, 0xC0, 0x03, 0xFF, 0xFF, 0xE7, 0xFF, 0xFF,
  0xCF, 0xFF, 0xFF, 0x9F, 0xFF, 0xFF, 0x3F, 0xFF, 0xFE, 0x7F, 0xFF, 0xFC, 0xFF, 0xFF, 0xF9, 0xFF,
  0xFF, 0xF0
};

uint8_t bmpPMOSFET[] PROGMEM = {

  23, 0, // width
  34, 0, // height
  0x3F, 0xFF, 0xFE, 0x7F, 0xFF, 0xFC, 0xFF, 0xFF, 0xF9, 0xFF, 0xFF, 0xF3, 0xFF, 0xFF, 0xE7, 0xFF,
  0xFF, 0xCF, 0xFF, 0xFF, 0x9F, 0xFF, 0xFF, 0x00, 0x0C, 0xFE, 0x00, 0x19, 0xFF, 0xFF, 0x33, 0xFF,
  0xFE, 0x67, 0xFF, 0xFF, 0xCF, 0xFF, 0xBF, 0x9F, 0xFC, 0x73, 0x3F, 0xE0, 0xE6, 0x7F, 0x80, 0x0C,
  0xFE, 0x00, 0x19, 0xFC, 0x07, 0x33, 0xF9, 0x8E, 0x67, 0xF3, 0xDF, 0xCF, 0xE7, 0xFF, 0x9F, 0xCF,
  0xF3, 0x3F, 0x9F, 0xE6, 0x7F, 0x00, 0x0C, 0x00, 0x00, 0x18, 0x00, 0xFF, 0xFF, 0xF9, 0xFF, 0xFF,
  0xF3, 0xFF, 0xFF, 0xE7, 0xFF, 0xFF, 0xCF, 0xFF, 0xFF, 0x9F, 0xFF, 0xFF, 0x3F, 0xFF, 0xFE, 0x7F,
  0xFF, 0xFC
};

uint8_t bmpNJFET[] PROGMEM = {
  21, 128, // width (run-length encoded)
  30, 0, // height
  0x02, 0x13, 0x02, 0x13, 0x02, 0x13, 0x02, 0x13, 0x02, 0x13, 0x02, 0x13, 0x02, 0x13, 0x02, 0x13, 0x02, 0x05, 0x02, 0x0C,
  0x02, 0x05, 0x02, 0x0C, 0x09, 0x0C, 0x09, 0x13, 0x02, 0x13, 0x02, 0x13, 0x02, 0x13, 0x02, 0x06, 0x01, 0x0C, 0x02, 0x04,
  0x03, 0x0C, 0x02, 0x02, 0x05, 0x05, 0x2C, 0x05, 0x02, 0x02, 0x05, 0x05, 0x02, 0x05, 0x02, 0x04, 0x03, 0x05, 0x02, 0x0D,
  0x01, 0x05, 0x02, 0x13, 0x02, 0x13, 0x02, 0x13, 0x02, 0x13, 0x02, 0x13, 0x02, 0x13, 0x02, 0x13
};

uint8_t bmpPJFET[] PROGMEM = {
  21, 128, // width (run-length encoded)
  30, 0, // height
  0x00, 0x13, 0x02, 0x13, 0x02, 0x13, 0x02, 0x13, 0x02, 0x13, 0x02, 0x13, 0x02, 0x13, 0x02, 0x13, 0x02, 0x0C, 0x02, 0x05,
  0x02, 0x0C, 0x02, 0x05, 0x02, 0x0C, 0x09, 0x0C, 0x09, 0x0C, 0x02, 0x13, 0x02, 0x13, 0x02, 0x0F, 0x01, 0x03, 0x02, 0x0D,
  0x03, 0x03, 0x02, 0x0B, 0x05, 0x03, 0x02, 0x07, 0x2A, 0x04, 0x05, 0x03, 0x02, 0x05, 0x02, 0x06, 0x03, 0x03, 0x02, 0x05,
  0x02, 0x08, 0x01, 0x0A, 0x02, 0x13, 0x02, 0x13, 0x02, 0x13, 0x02, 0x13, 0x02, 0x13, 0x02, 0x13, 0x02, 0x13, 0x02
};

uint8_t bmpPDiodeBig[] PROGMEM = {
  20, 128, // width run-length encoded
  24, 0, // height
  0x00, 0x09, 0x02, 0x12, 0x02, 0x12, 0x02, 0x12, 0x02, 0x12, 0x02, 0x12, 0x02, 0x09, 0x14, 0x01, 0x12, 0x03, 0x10, 0x05,
  0x0E, 0x07, 0x0C, 0x09, 0x0A, 0x0B, 0x08, 0x0D, 0x06, 0x0F, 0x04, 0x11, 0x02, 0x09, 0x28, 0x09, 0x02, 0x12, 0x02, 0x12,
  0x02, 0x12, 0x02, 0x12, 0x02, 0x12, 0x02, 0x09
};

uint8_t bmpNDiodeBig[] PROGMEM = {
  20, 128, // width run-length encoded
  24, 0, // height
  0x00, 0x09, 0x02, 0x12, 0x02, 0x12, 0x02, 0x12, 0x02, 0x12, 0x02, 0x12, 0x02, 0x09, 0x28, 0x09, 0x02, 0x11, 0x04, 0x0F,
  0x06, 0x0D, 0x08, 0x0B, 0x0A, 0x09, 0x0C, 0x07, 0x0E, 0x05, 0x10, 0x03, 0x12, 0x01, 0x14, 0x09, 0x02, 0x12, 0x02, 0x12,
  0x02, 0x12, 0x02, 0x12, 0x02, 0x12, 0x02, 0x09
};


const char* txp[6] = {"min: ", "incr:", "max: ", "mist ", "inst ", "mast "};
const char* txt[9] = {"I-base [uA]", "V-gate [0.1V] ", "V-gate [0.1V] ", "Bluet.", "CCS", "x-scale[V] : ", "y-scale[mA]: ", "Batt:", "I-diode [mA]"};
const char* txc[5] = {"pnp/npn", "MosFET", "J-FET ", "n-DEPL", "Diode"};
const char* txf[9] = {"CurveTracer", "Curve+Bluetooth", "Curve+SD-Card", "Curve+Bluet.+SD-C", "const.Voltage", "const.Current", "cC:Step-Up/Down", "cC:Step-Up", "cC:Step-Down"};
const char* txk[10] = {" ", " npn", " n-Mosfet", " n-jFet", " n-Diode", " pnp", " p-Mosfet", " p-jFet", " p-Diode", " n-Depl.Mos"};
const char* sdi[2] = {"SD-Card inserted ?", "SD-initial. done"};
const char* sdo[3] = {"sd000001.txt", "SD opened: ", "SD not opned: "};
/*
  const char* pmosf  = "p-MOSFET";
  const char* nmosf  = "n-MOSFET";
  const char* pjfet  = "p-JFET";
  const char* njfet  = "n-JFET";
  const char* pdiod  = "pDiode";
  const char* ndiod  = "nDiode";
*/

const int8_t lf = 10;   // linefeed
const uint16_t ft[4][10] =
  //---- 0---1---2---3---4---5---6---7---8---9---
{ 19, 37, 37, 19, 19, 19, 19, 19, 19, 37,   // h
  82, 123, 263, 289, 129, 129, 129, 280, 280, 162, // x
  7,  0,  0, 100, 98, 148, 198, 148, 198,  0, // y
  32, 38, 38, 20, 36, 36, 44, 35, 40, 98
};  // w 36/43 33/40  8:34
//---- 0---1---2---3---4---5---6---7---8---9---
const int8_t xs_t[] = {0, 1, 2, 3, 4, 6, 12};   // x_scale
const int8_t ys_t[] = {0, 2, 5, 10, 20, 50, 100}; // y_scale
//-----------------0-------1-------2-----------3--------4--------5-------6--------7----------8----
enum TkindDUT {tkNothing, tkNPN, tkNMOSFET, tkNJFET, tkNDIODE, tkPNP, tkPMOSFET, tkPJFET, tkPDIODE};
//-----------------0-------1-------2-----------3--------4--------5-------6--------7----------8----
int8_t /*TkindDUT*/ curkind;
//enum TclassDUT {tcBipolar, tcMOSFET, tcJFET};//0,1,2
int8_t tcBipolar = 0;
int8_t tcMOSFET  = 1;
int8_t tcJFET    = 2;

int8_t CurDUTclass = tcBipolar, class_o = tcBipolar;
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
void loop(void) {
  tft.setFreeFont(FF33);
  clearMenu();
  drawFunctions();             // CT or other (CCV/CCS) ...
  // tft.println(" nach clear"); delay(1000);
  // Serial.println(" loop: nach clear");
#ifdef  NAME_D
  setDevName();                // device-Name
#endif


ser1_read:

// tft.print("vor readserial nrk: ");
  s_isr32 = 0;
  int8_t class_0123 = 9,s_param=0;
  nrk = readSerial();
// tft.println(nrk);
  if (nrk > 0) {  // connection to TT: DUT found
    readParamEEPROM(CurDUTclass);
    retc = ExecSetupMenu( mini, maxi, inci);
 // clearMenu();
  }
  else {  // no connection to TT or no DUIT found
 // CurDUTclass = EEPROM.readChar(99);
 // Serial.print("Class: ");Serial.println(CurDUTclass);
 //  s_diode = 0;
 // readParamEEPROM(readChar(99));           // params from last run
  
  while (1) {
#ifdef TOUCH
  
  if (s_touchi == 1) {
    s_touchi = 0;
    uint16_t z = tft.getTouchRawZ();

    if (z > 250)  {
      getTouchCoord();   // x y between 320 and 240
   //   DrawBox(235,0,110,35, TFT_BLACK);
   //   DrawIntAt(235,14, valx, 1, TFT_WHITE);
   //   DrawIntAt(235,33, valy, 1, TFT_WHITE);
   //   DrawIntAt(280,14, z, 1, TFT_WHITE);
      if (valx > 36 and valx < 75) {                                  // select class ##########################
        if (valy < 90) {  // Transistor / Diode
       //   DrawStringAt(85,63,"Tran/Diode",1,TFT_WHITE);
         
          if (class_0123 == 9 or class_0123 == 1) class_0123 = 0;
          else  class_0123 = 1;
          dcl = class_0123;
          delay(50);
          goto newcross;
        }
        else if (valy < 170) {  // MosFet
       //   DrawStringAt(85,143,"Mosfet",1,TFT_WHITE);
          dcl = 2;
          class_0123 = 2;
          delay(20);
          goto newcross;
        }
        else if (valy > 180 and valy < 220) {  // jFet
       //   DrawStringAt(85,223,"J-Fet",1,TFT_WHITE);
          dcl = 3;
          class_0123 = 3;
          delay(20);
          goto newcross;
        }
      }
           
      else if
       (valx > 90 and valx < 125 and      // functions
        valy >  5 and valy < 160)      {  // 0=CT,1=ct+Blue,2=CT+SD,3=CT+Blu+SD,4=const.Volt.Source
        if      (valy <  30) funcy = 0;
        else if (valy <  60) funcy = 1;
        else if (valy <  90) funcy = 2;
        else if (valy < 120) funcy = 3;
        else if (valy < 160) funcy = 4; 
        if (funcy < 5) {
          paintCrossFuncy(funcy);                     // activate function 0...4 
        }
      }
      else if
        (valx > 130 and valx < 290 and
         valy > 200 and valy < 230)    {
        if      (valx < 145) funcx = 5;
        else if (valx < 188) funcx = 6;
        else if (valx < 255) funcx = 7;
        else if (valx < 285) funcx = 8;
        if (funcx < 9) {
          paintCrossFuncx(funcx);                     // activate function 5...8 
        }
      } 
      else if (valx > 95 and valx < 120 and valy > 200 and valy < 230 and funcx < 9) {
        l_func = 9;
        if      (funcyo < 5) l_func = funcyo;
        else if (funcxo < 9) l_func = funcxo;
       
        if (l_func == funcyo) {  
          DrawBox(96,  9 + funcyo*32, 15, 15, TFT_BLACK);      // no focus
          DrawBox(99, 12 + funcyo*32,  9,  9, TFT_WHITE);
        }
        if (l_func == funcxo) {  
          DrawBox(130 + (funcxo-5) * 45 + 4, 212 + 4, 15, 15, TFT_BLACK);
          DrawBox(130 + (funcxo-5) * 45 + 7, 212 + 7, 9, 9, TFT_WHITE);
       
        }
        if (l_func < 9) {
          s_blue  = l_func;
          s_param = 1;
          goto nxt_run;
        }


           
      } 
      else if (valy >= 238);
    }  // z > 1000
  }    // s_touchi

#endif
      if (s_isr32 == 1) goto nxt_run;
      if (Serial.available() > 0) goto ser1_read; //break;
      if (rota2 != 0) {
        if (rota2 > 0 )      dcl--;
        else if (rota2 < 0)  dcl++;
        if      (dcl > 3) dcl = 0;  //r2
        else if (dcl < 0) dcl = 3;  //r2
        rota2 = 0;
   newcross:     
        DrawBox( 30, CurDUTclass * 80 + 52, 18, 18, TFT_WHITE); // erase old Cross
     // Serial.print("dcl ");Serial.print(dcl);Serial.print(" CDC ");Serial.print(CurDUTclass);Serial.print(" rota2 ");Serial.println(rota2);
        CurDUTclass = 0;
        s_new = 0;
        if (dcl >= 2) {  // mosfet, jFet
          CurDUTclass = dcl - 1; //r2 new
          s_new = CurDUTclass;
          s_diode = 0;
        }  
        else {   // diode or pnp/npn
          if (dcl == 0) {
            s_diode = 1;      // paint diode curves
            s_dsign = 1;      // change icon to diode on screen
            DrawCheckBox( CurDUTclass, r_g_b(0xFF, 0xFF, 0x80)); // diode
          }
          else {              // old: diode
            s_diode = 0;      // paint transistor curves
            s_dsign = 0;      // change icon to pnp/npn on screen
            DrawCheckBox( CurDUTclass, r_g_b(0xFF, 0xFF, 0x80));   // pnp/npn
          }   
        }  // else  : diode or pnp/npn
        paintCross(); // erase old cross and place new Cross
       
     // Serial.println(dcl);
      }  // if (rota2 != 0
      if (s_isr32 == 1 or s_param == 1) { 
   nxt_run:  
        s_param = 0;   
        DrawBox(81,0,238,240,TFT_BLACK);     // erase functions-menu
       // EEPROM.writeChar(20*CurDUTclass, CurDUTclass);    // 0=bipolar,1=Mosfet,2=J-Fet
        readParamEEPROM(CurDUTclass);  //######################///
        class_o = CurDUTclass;
        retc = ExecSetupMenu( mini, maxi, inci);  //#####################<<<<<<<<<<<<<<<<<<<<<<<
        break;
      }
      
    } // while
    s_isr32 = 0;
  } // else

}




void initSD_Card() {
#ifdef SD_C
  s_isr32 = 0;
  debugln("initialization SD-Card :");
 // SPI.beginTransaction(settingsM);
  while (!SD.begin(pin_SD_CS)) {

    debugln("initialization failed. Things to check:");
    debugln(" 1. is a card inserted?");
    debugln(" 2. is your wiring correct?");
    debugln(" 3. did you change the SD_CS-pin (8?) ?");
    //   debugln("Note: press reset button on the board and reopen this Serial Monitor after fixing your issue!");
    DrawStringAt(178, 70, "SD inserted ?", 1, TFT_MAGENTA); // 173 SD
    if (s_isr32 == 1) { 
      s_blue = 0;
      s_isr32 = 0;
      delay(40);
      s_isr32 = 0;
      DrawStringAt(178, 70, sdi[0]/*"SD-Card inserted ?"*/, 1, TFT_BLACK);   // SD
      return;
    }  
  }

  debugln("initialization done.");
  DrawStringAt(178, 70, "SD inserted ?", 1, TFT_BLACK);   // SD
  DrawStringAt(178, 70, "SD-initialized", 1, TFT_BRIGHTBLUE);  // SD

#endif

}



void openSD_Card() {
#ifdef SD_C

  // open the file. note that only one file can be open at a time,
  // so you have to close this one before opening another.
  String file_p = sdo[0]/*"sd654321.txt"*/;       // file-name preset for ESP32

  if (efnr == 1) file_p.setCharAt(1, 'P'); //0,
  else           file_p.setCharAt(1, 'N'); //0,
  if      (CurDUTclass == tcBipolar) file_p.setCharAt(2, '0'); //0=bipolar//1,
  else if (CurDUTclass == tcMOSFET)  file_p.setCharAt(2, '1'); //1=Mosfet //1,
  else if (CurDUTclass == tcJFET)    file_p.setCharAt(2, '2'); //2=j-Fet  //1,
#ifdef NAME_D
  if (l_devna > 2) {
    for (int in = 0; in < 6; in++) {
      file_p.setCharAt(in + 3, name_t[in]); //+2
    }
  }
#endif
  dataFile = SD.open(file_p, FILE_WRITE); //"datalog.txt", FILE_WRITE);
  if (dataFile) {
    DrawStringAt(178, 70, "file: ", 1, TFT_BRIGHTBLUE);  // 173 SD
    tft.print(file_p); //DrawString(file_p,1,TFT_BRIGHTBLUE);  // SD
    dataFile.close();  // test######################################################
  }
  else {     // if the file isn't open, pop up an error:
    DrawStringAt(178, 70, "file not open: ", 1, TFT_ORANGE);  // SD
    tft.print(file_p);   //DrawString(file_p,1,TFT_ORANGE);  // SD
  }

  delay(3000);

#endif

}

void drawButton_N_P( uint16_t xleft, uint16_t ytop, uint16_t dim_x, uint16_t dim_y, char n_p_tx, uint16_t col_tx, uint16_t col_back) {

  DrawBox(xleft, ytop, dim_x, dim_y, TFT_DARKGREY);
  DrawFrame(xleft, ytop, dim_x, dim_y, TFT_WHITE);
  DrawBox(xleft + 2, ytop + 2, dim_x - 4, dim_y - 4, col_back);
  DrawCharAt( xleft + 5, ytop + 27, n_p_tx, 2, col_tx);  //###size 2###

}
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

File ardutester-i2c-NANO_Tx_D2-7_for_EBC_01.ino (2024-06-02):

/*                      \\\|///
                        \\  - -  //
                         (  @ @  )
  /--------------------oOOo-(_)-oOOo---------------------\
  |                                                      |
  |                                                      |
  |    Transistor Tester for Arduino (version 1.08a)     |
  |                                                      |
  |  based on code: Karl-Heinz Kubbeler (version 1.08k)  |
  |                                                      |
  |                                                      |
  |                            Oooo                      |
  \--------------------oooO----(   )---------------------/
                     (   )    ) /
                        \ (    (_/
                         \_)                            */

#include <Arduino.h>
#include <avr/io.h>
#include <util/delay.h>
#include <avr/sleep.h>
#include <stdlib.h>
#include <string.h>
#include <avr/eeprom.h>
#include <avr/pgmspace.h>
#include <avr/wdt.h>
#include <avr/interrupt.h>
#include <math.h>
#include <stdint.h>
#include <avr/power.h>
#include <Wire.h> 


#include <LiquidCrystal_I2C.h>
LiquidCrystal_I2C lcd(0x3F, 16, 2);  //LiquidCrystal_I2C lcd(0x27, 16, 2);


int16_t ifc, ifi,ipi;


unsigned int blinkMillis;
unsigned int buttonMillis;

int val = 0,base;
byte i = 0;
int prev_x = 0, prev_y = 0;
bool ExecSerialTx = false; // send scans to PC
bool SendAdcValues = false; // send ADC values to PC

const int pin_PUSHBUT     =  0;  // PUSH-Button     RX-Pin
//const int pin_PUSHBUT     =  2;  // PUSH-Button     ISR-Pin
//const int pin_ADC_SW      =  6;  // D6 connect ADC0,1,2 with TP1,2,3
const int pin_ADC_SW      = 17;  // A3 connect ADC0,1,2 with TP1,2,3
const int pin_ADC_12V     = 21;  // A7
  
const unsigned long TimeoutPeriod = 60000;

volatile int8_t s_isr = 0, s_isr1, s_isr2, s_two1, s_rota1 = 0,s_auto=0,s_vgs=0;
volatile long time_l = 0, time1_o = 0, times_n, times_o = 0;
unsigned long seconds = 1000L; //Notice the L
unsigned long minutes = seconds * 60;


// be careful using these inside if statements:
//#define SerialPrint(s) {if (ExecSerialTx) Serial.print(s);}
//#define SerialPrintLn(s) {if (ExecSerialTx) Serial.println(s);}

int8_t s_min,s_max,s_sum,error_i=0,s_test=1;
//---------------0,         1,     2,      3,         4,         5,       6,      7,         8
enum TkindDUT {tkNothing, tkPNP, tkNPN, tkPMOSFET, tkNMOSFET, tkPJFET, tkNJFET, tkPDiode, tkNDiode};
TkindDUT curkind;
uint8_t kind_nr = curkind;
enum TclassDUT {tcBipolar, tcMOSFET, tcJFET}; // 0,1,2
TclassDUT CurDUTclass = tcBipolar;

char intface_t[] = {' ','N','D','E','B','C','X'};
             
int8_t sw1,sw2,sw3;

volatile int8_t s_switch=0;

int imax = 480;
int icr=0,uce=0,uop=0,u12=0;

// ******** config options for your Semiconductor tester

// Every changing of this Makefile will result in new compiling the whole
// programs, if you call make or make upload.

#define MCU atmega328p
#define F_CPU 16000000UL

// Select your language:
// Available languages are: LANG_ENGLISH, LANG_GERMAN, LANG_POLISH, LANG_CZECH, LANG_SLOVAK, LANG_SLOVENE,
//                          LANG_DUTCH, LANG_BRASIL, LANG_RUSSIAN, LANG_UKRAINIAN
//#define LANG_ENGLISH
#define LANG_GERMAN
// The LCD_CYRILLIC option is necessary, if you have a display with cyrillic characterset.
// This lcd-display don't have a character for Ohm and for u (micro).
// Russian language requires a LCD controller with russian characterset and option LCD_CYRILLIC!
//#define LCD_CYRILLIC

// The LCD_DOGM option must be set for support of the DOG-M type of LCD modules with ST7036 controller.
// For this LCD type the contrast must be set with software command.
//#define LCD_DOGM


// The WITH_SELFTEST option enables selftest function (only for mega168 or mega328).
//#define WITH_SELFTEST

// AUTO_CAL will enable the autocalibration of zero offset of capacity measurement and
// also the port output resistance values will be find out in SELFTEST section.
// With a external capacitor a additionally correction of reference voltage is figured out for 
// low capacity measurement and also for the AUTOSCALE_ADC measurement.
// The AUTO_CAL option is only selectable for mega168 and mega328.
//#define AUTO_CAL

// FREQUENCY_50HZ enables a 50 Hz frequency generator for up to one minute at the end of selftests.
//#define FREQUENCY_50HZ

// The WITH_AUTO_REF option enables reading of internal REF-voltage to get factors for the Capacity measuring.
#define WITH_AUTO_REF
// REF_C_KORR corrects the reference Voltage for capacity measurement (<40uF) and has mV units.
// Greater values gives lower capacity results.
#define REF_C_KORR 12
// REF_L_KORR corrects the reference Voltage for inductance measurement and has mV units.
#define REF_L_KORR 40
// C_H_KORR defines a correction of 0.1% units for big capacitor measurement.
// Positive values will reduce measurement results.
#define C_H_KORR 0

// The WITH_UART option enables the software UART (TTL level output at Pin PC3, 26).
// If the option is deselected, PC3 can be used as external voltage input with a
// 10:1 resistor divider.
//#define WITH_UART

// The CAP_EMPTY_LEVEL  defines the empty voltage level for capacitors in mV.
// Choose a higher value, if your Tester reports "Cell!" by unloading capacitors.
#define CAP_EMPTY_LEVEL 4

// The AUTOSCALE_ADC option enables the autoscale ADC (ADC use VCC and Bandgap Ref).
#define AUTOSCALE_ADC
#define REF_R_KORR 3

// The ESR_ZERO value define the zero value of ESR measurement (units = 0.01 Ohm).
//#define ESR_ZERO 29
#define ESR_ZERO 20

// NO_AREF_CAP tells your Software, that you have no Capacitor installed at pin AREF (21).
// This enables a shorter wait-time for AUTOSCALE_ADC function.
// A capacitor with 1nF can be used with the option NO_AREF_CAP set.
#define NO_AREF_CAP

// The OP_MHZ option tells the software the Operating Frequency of your ATmega.
// OP_MHZ 16

// Restart from sleep mode will be delayed for 16384 clock tics with crystal mode.
// Operation with the internal RC-Generator or external clock will delay the restart by only 6 clock tics.
// You must specify this with "#define RESTART_DELAY_TICS=6", if you don't use the crystal mode.
//#define RESTART_DELAY_TICS 6

// The USE_EEPROM option specify where you wish to locate fix text and tables.
// If USE_EEPROM is unset, program memory (flash) is taken for fix text and tables.
//#define USE_EEPROM

// Setting EBC_STYPE will select the old style to present the order of Transistor connection (EBC=...).
// Omitting the option will select the 123=... style.  Every point is replaced by a character identifying 
// type of connected transistor pin (B=Base, E=Emitter, C=Collector, G=Gate, S=Source, D=Drain).
// If you select EBC_STYLE=321 , the style will be 321=... , the inverted order to the 123=... style.
//#define EBC_STYLE
//#define EBC_STYLE 321
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

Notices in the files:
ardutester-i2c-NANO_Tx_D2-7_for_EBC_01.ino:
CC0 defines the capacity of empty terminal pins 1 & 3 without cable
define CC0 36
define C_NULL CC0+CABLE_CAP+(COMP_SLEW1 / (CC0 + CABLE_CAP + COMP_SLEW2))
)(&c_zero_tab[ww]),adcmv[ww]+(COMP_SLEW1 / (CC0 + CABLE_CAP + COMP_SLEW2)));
